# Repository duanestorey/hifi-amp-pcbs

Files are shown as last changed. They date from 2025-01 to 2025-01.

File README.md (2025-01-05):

## Hi-Fidelity Amplifier With Active-Crossovers and Room Correction

These are the PCBs representing a two-year passive effort to create, from scratch, an entire hi-fi amplifier with built-in DSP support for active crossovers and room 
correction.  You can [explore the individual PCBs for this project here](/pcbs).

### Overview

The amplifier has the following specifications:

* Four LM3886 68W amplifier channels in two monoblocks
* Five line-level RCA analog inputs
* One phono/vinyl RCA input with built-in amplifier and RIAA correction
* Four 192kHz/24-bit digital SPDIF inputs and one TOSLINK optical
* Multiple 192kHz/24-bit Burr-brown digital to analog converters
* IR remote connection, and built-in web server for configuration and web-app access
* Custom digital signal processor with active-crossovers and room correction ability based on biquad filters and parametric EQ
* Over-the-air code updates and wifi diagnostic information 

### Project Style Guide

#### Power Monitors

There are several INA260 power meters.  

1) MAIN Digital/Analog PSU monitor, address GND/SCL
2) MAIN Positive rail for channel amplifiers, address SCL/GND
3) 7V to 5V converter, address GND/GND
4) 7V to 3V converter, address GND/3V
5) Positive analog converter,  3V/GND
6) Entire 7V converter, 3V/3V

#### Temperature Sensors

1) Microprocessor board, address GND/GND
2) Digital/Analog PSU, address GND/3V#
3) Monoblocks 1, address 3V3/GND and 3V3/3V3
4) DSP, address float/GND

#### LED lights and resistors

The following voltages and LED colours should be used for consistency. In general, all LEDs are set at 2ma of current are 0603 size.

##### Digital Voltages

- 3.3V - Blue, set to ~2ma using 150R 
- 5.0V - Red, set to ~2ma using 1.3K

##### Analog Voltages

* +3.3V - Yellow, set to ~2ma using 620R
* +9.5V - Yellow, set to ~2ma using 3.6K
* -9.5V - Blue, set to ~2ma using 3.3K
* +34V - Yellow, set to ~2ma using 16K
* -34V - Blue, set to ~2ma using 16K
* 12V - Red, set to ~2ma using 4.7K
* Positive DC - Yellow, set to 2ma
* Negative DC - Blue, set to 2ma

#### SPDIF

- TODO: ADded more inputs
- TODO: Maybe add isolation transformers
- TODO: Change ground plane so SPDIF ground doesn't interfere with analog DAC ground

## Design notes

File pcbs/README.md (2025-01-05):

## Printed Circuit Boards

These are all the associated PCBs for the amplifier project.  They were all created in Kicad, and the boards optimized for production via JLCPCB.

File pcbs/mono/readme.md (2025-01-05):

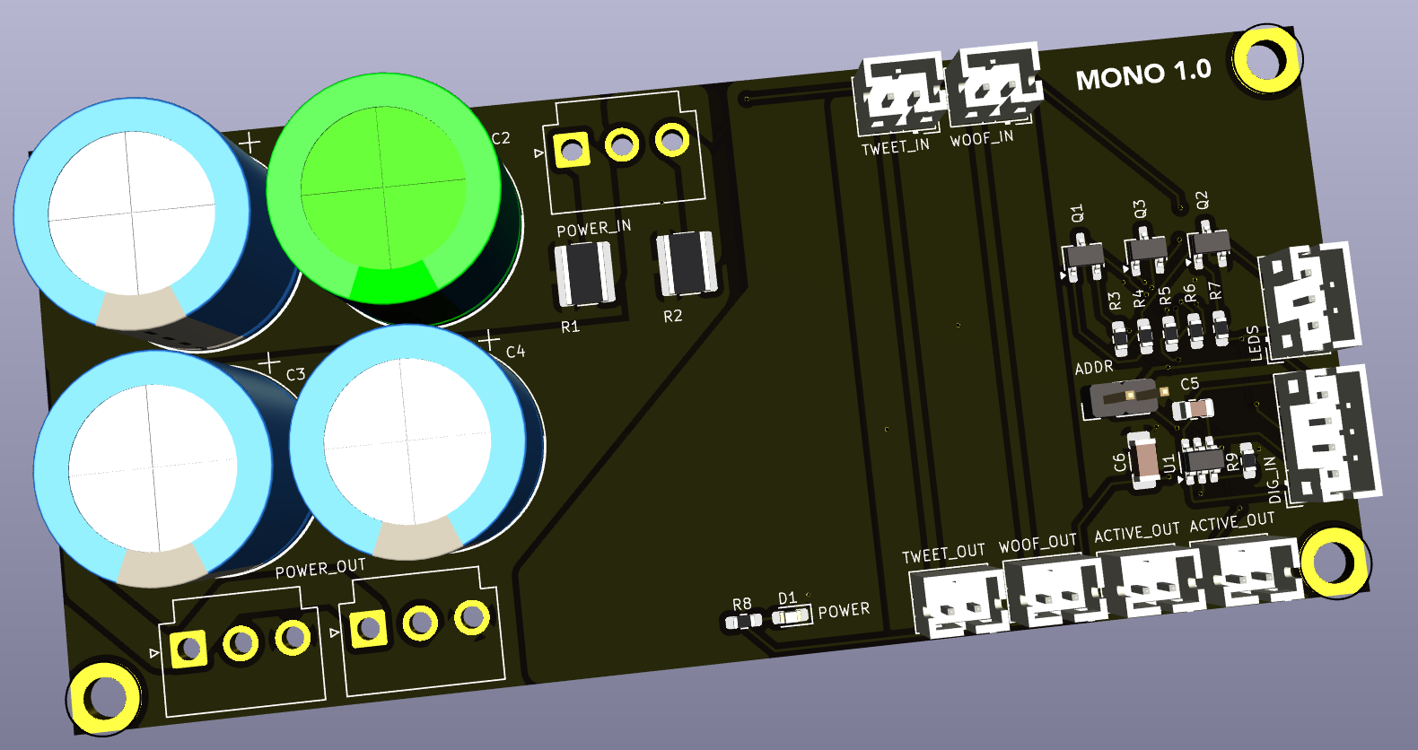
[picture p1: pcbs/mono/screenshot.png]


## Monoblocks

This board receives the main 7-pin XLR connections from the amplifier, which contain power, communincation, and control data.

### Version History

- 1.0: Initial Release

### Speciality Components

* TMP100 temperature sensor

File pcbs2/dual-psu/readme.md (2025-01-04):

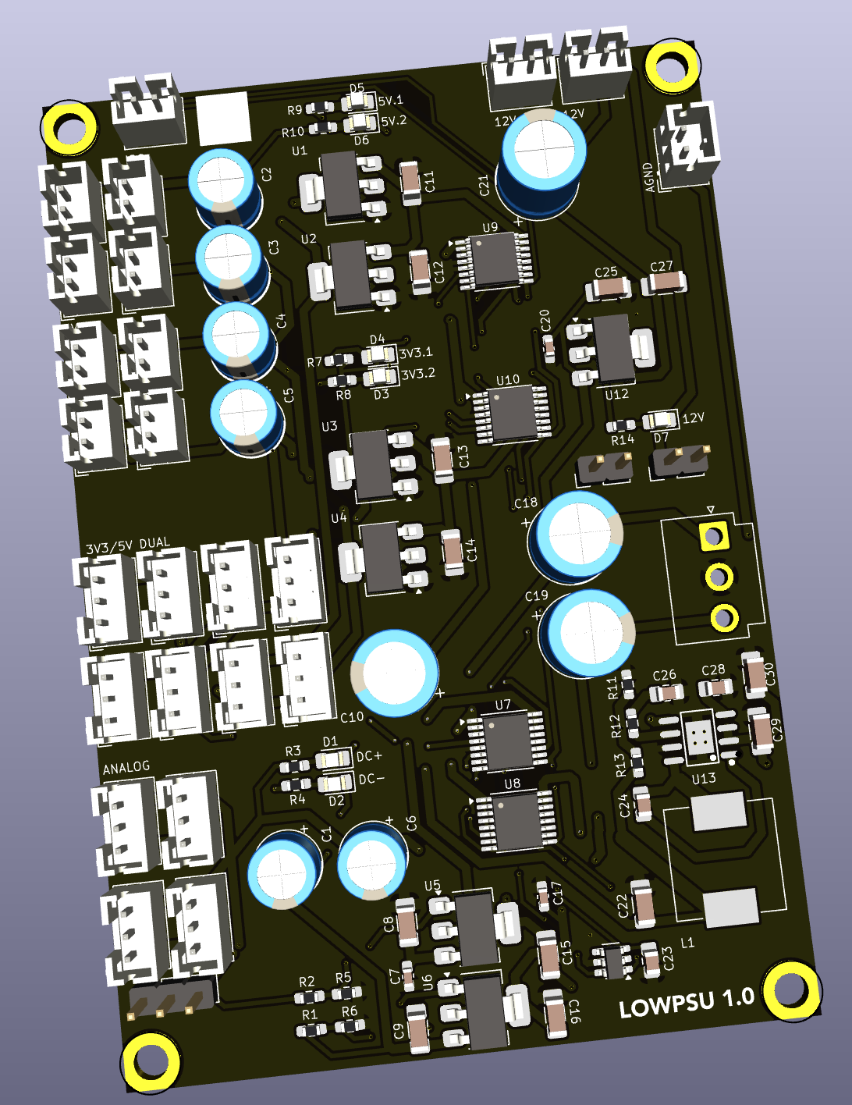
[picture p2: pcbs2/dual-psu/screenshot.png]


## Analog Power Supply for Operation Amplifier

This board produces a +/- 6.5V supply to be used with the DAC filter and the phono RIAA/pre-amplifier PCBs

### Version History

- 1.0: Initial Release

### Speciality Components

* LM317 & LM337 variable voltage regulators
* Myrra 44091 1.5VA with dual 6V secondaries

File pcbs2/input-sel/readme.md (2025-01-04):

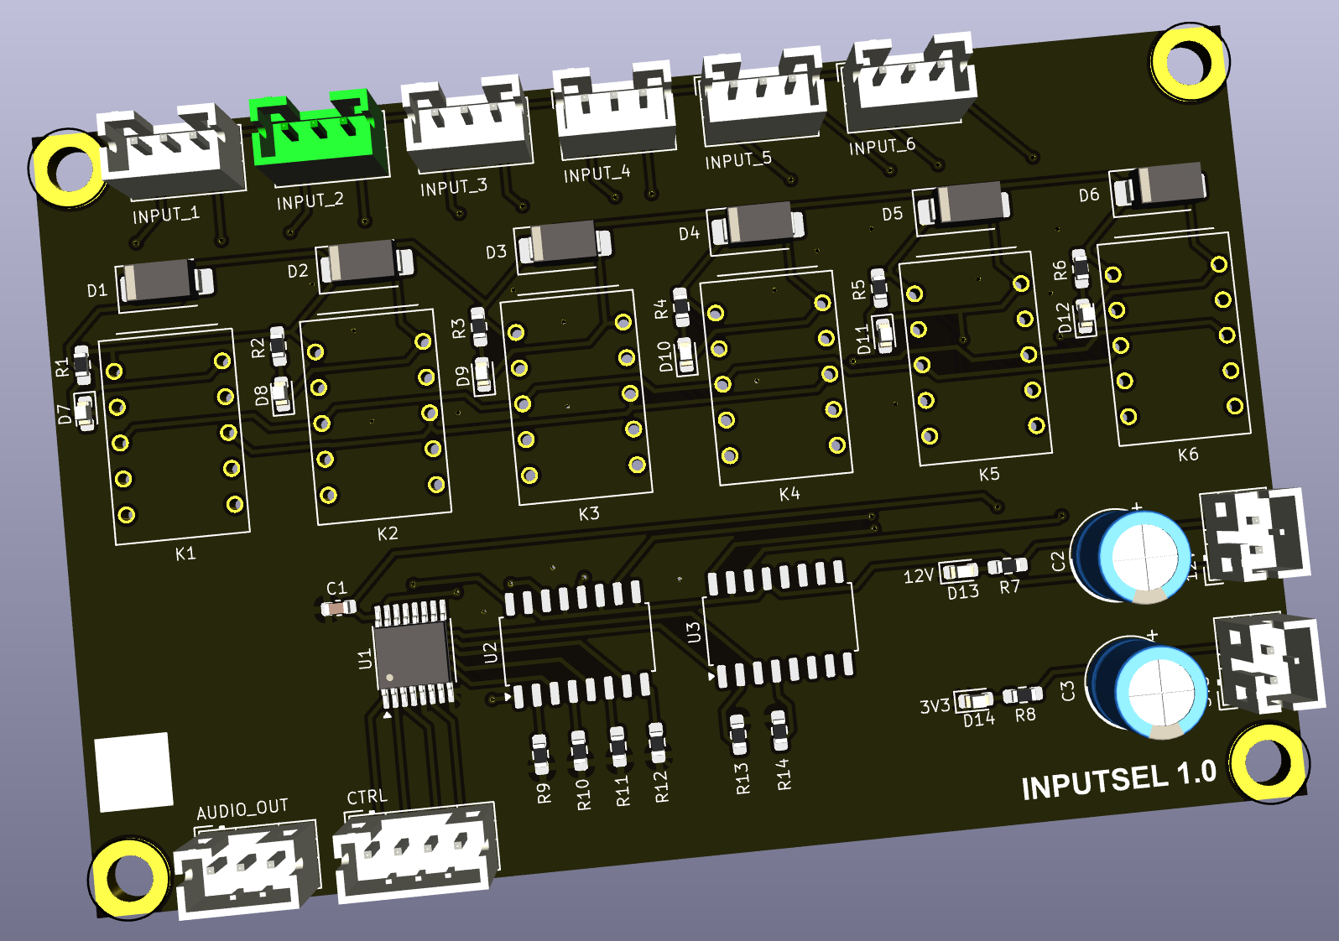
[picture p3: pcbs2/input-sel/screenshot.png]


## Line-Input Selector

This PCB allows switching of 4 analog stereo inputs and one 5.1 channel input into 5.1.  Channels that are missing
can be created.  It is based on the AX2358 IC.

### Version History

- 1.0: Initial Release
- 1.2: Did an initial build.  Seems like there is digital noise on the output, likely from the I2C signals sharing the audio ground.  This design now has a digital and analog ground on the board - it'll use the digital ground for the AX2358 IC, but use the analog ground for the channel outputs.

### Speciality Components

* AX2358 Channel switching IC
* Nichicon Muse ES 25V 10uF

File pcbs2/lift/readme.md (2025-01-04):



## Ground Lift

The heart of the amplifier is this microprocessor board based on the ESP32 WROOM 32 IC.

### Version History

- 1.0: Initial Release
- 1.1: Addressed issue with ESP32 programming transistors
- 1.2: Added missing pull-down resistor for relay/softstart 

### Speciality Components

* ESP32 WROOM 32
* FT232RL USB to UART converter
* TMP100 temperature sensor

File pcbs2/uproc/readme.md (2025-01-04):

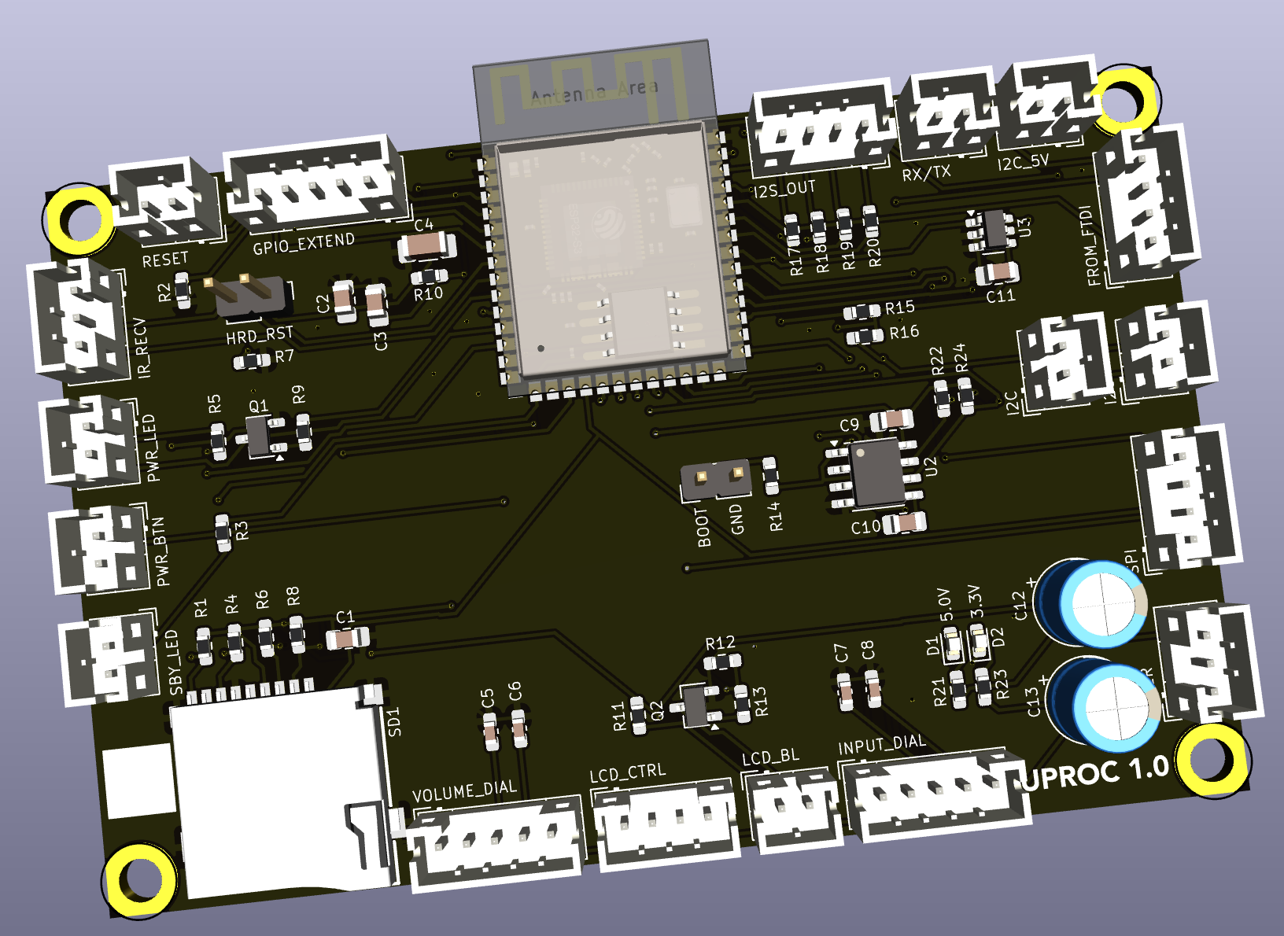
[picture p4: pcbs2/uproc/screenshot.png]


## Microprocessor Board

The heart of the amplifier is this microprocessor board based on the ESP32 WROOM 32 IC. Now supports a HAT.

### Version History

- 1.0: Initial Release
- 1.1: Addressed issue with ESP32 programming transistors
- 1.2: Added missing pull-down resistor for relay/softstart 

### Speciality Components

* ESP32 WROOM 32
* FT232RL USB to UART converter
* TMP100 temperature sensor

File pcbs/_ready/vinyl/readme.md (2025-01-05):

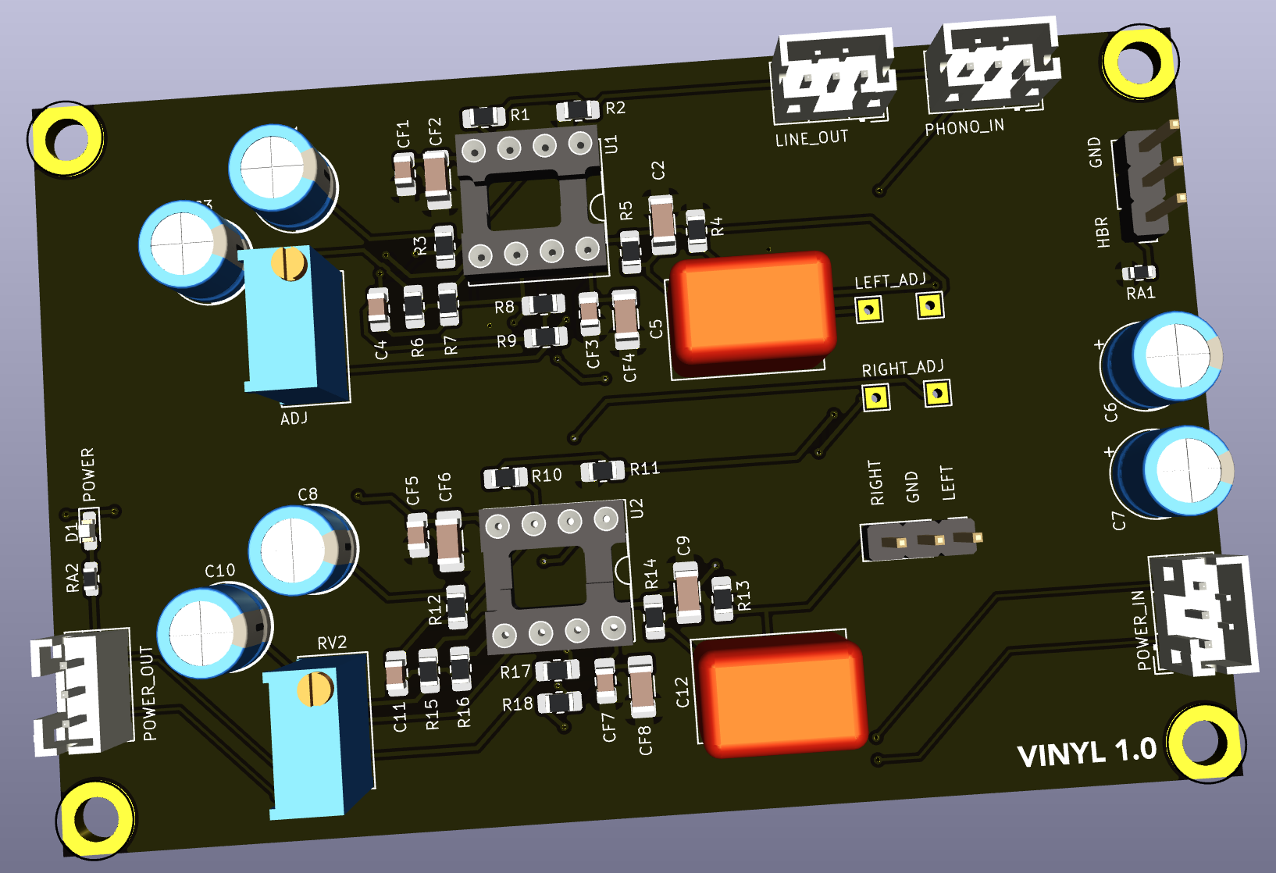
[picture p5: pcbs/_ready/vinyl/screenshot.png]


## Phono/Vinyl Pre-amp

This is a phono/vinyl pre-amp with adjustable gain from about 40dB up to 60dB. It is based almost entirely on the ESP Project 6 Hifi Phono Pre-amp.  All resistors are thin-film 603/805, and all capacitors are either Nichicon Muse ES bipolar electrolytics or C0G surface mount 1206 variants.

### Version History

- 1.0: Initial Release

### Speciality Components

* OPA1612 Burr Brown operation amplifiers
* Various C0G and thin film resistors
* Nichicon Muse ES 25V 10uF

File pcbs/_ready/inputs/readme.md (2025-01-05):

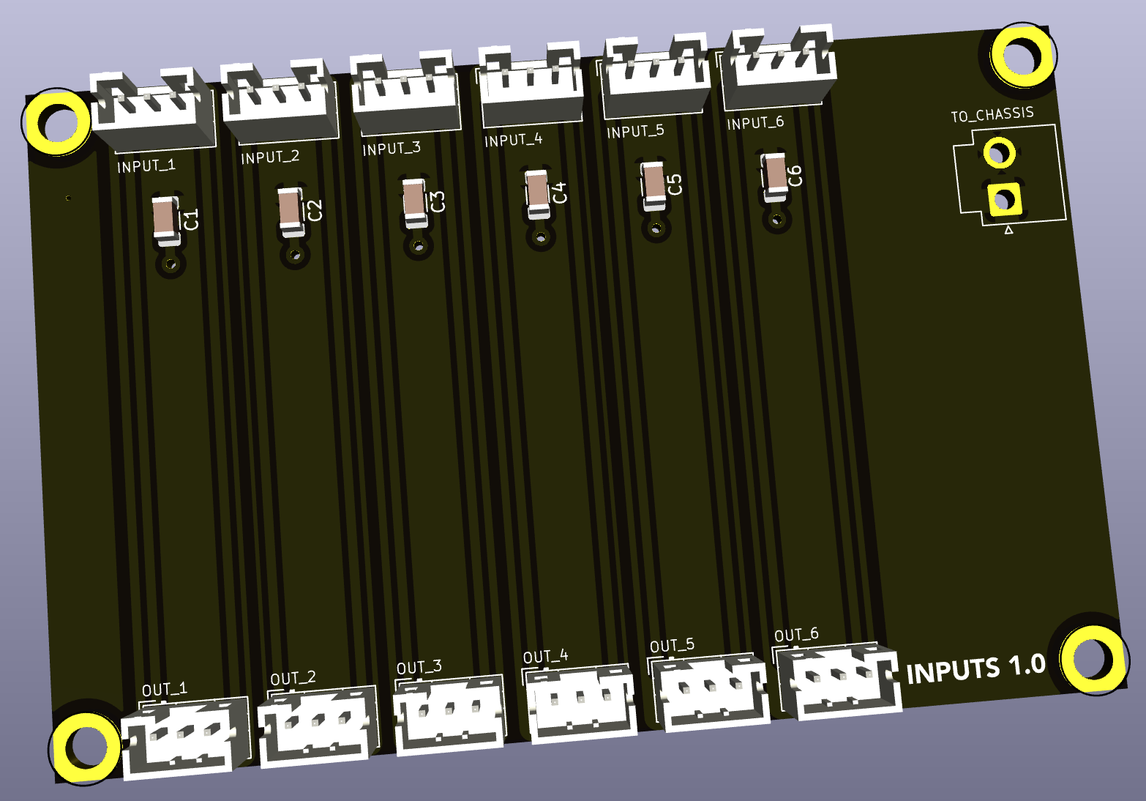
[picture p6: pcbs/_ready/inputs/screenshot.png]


# Input board

This is a simple board meant to proxy six RCA input signals from one part of the amplifier to the other without long physical cable runs. It also provides a chassis GND connection via a capacitor to shunt stray EMI to chassis ground.

## Version History

- 1.0: Initial Release

## Speciality Components

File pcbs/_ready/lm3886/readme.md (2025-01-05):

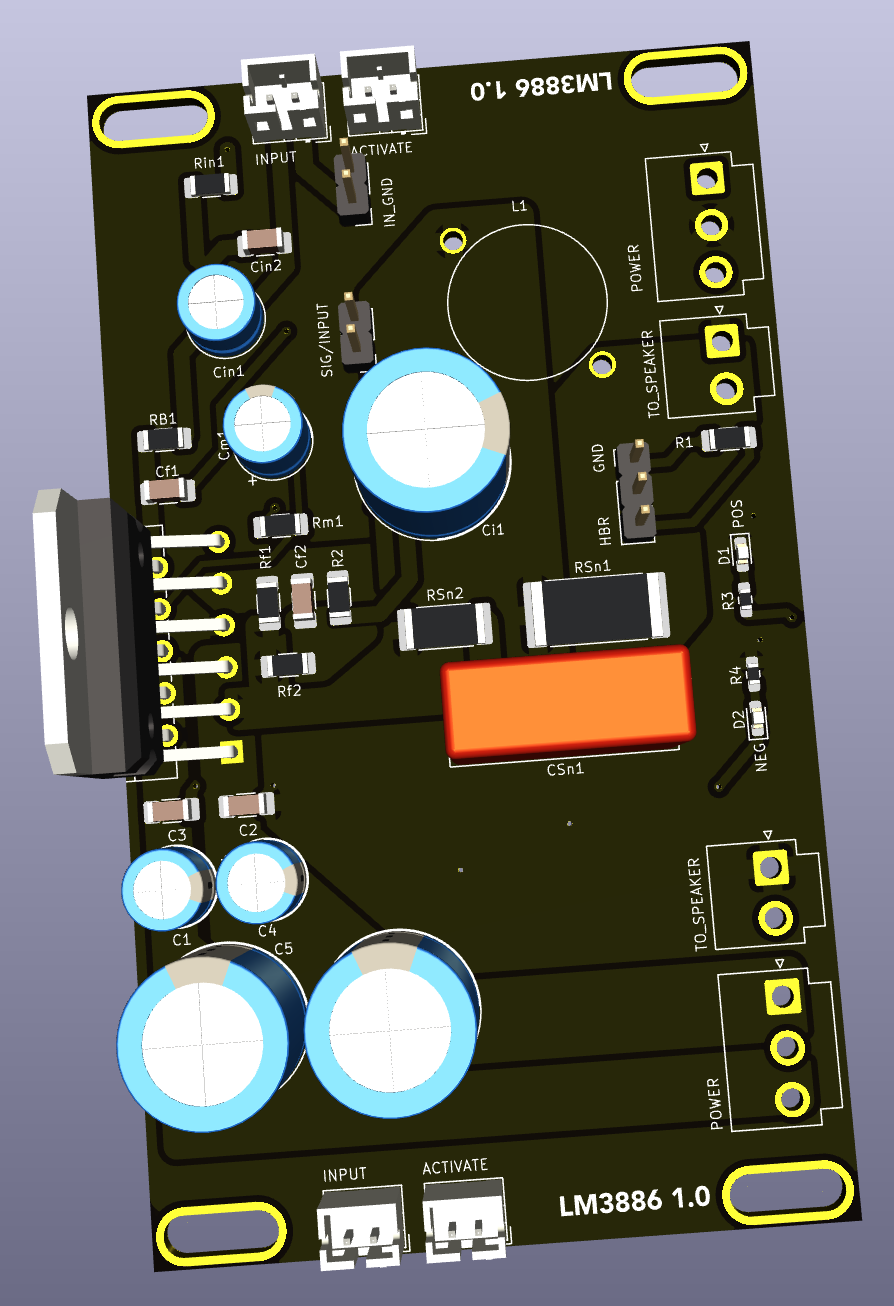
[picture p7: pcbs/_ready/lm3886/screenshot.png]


## LM3886

This board is meant to be reversable (top-to-bottom), and contains the highly rated, high fidelity LM3886 audio amplifier IC. Two of these boards are used in each monoblock to amplifier the associated tweeter and woofer channels.

### Version History

- 1.0: Initial Release

### Speciality Components

* LM3886 68W audio amplifier IC
* 500nH air core Inductor

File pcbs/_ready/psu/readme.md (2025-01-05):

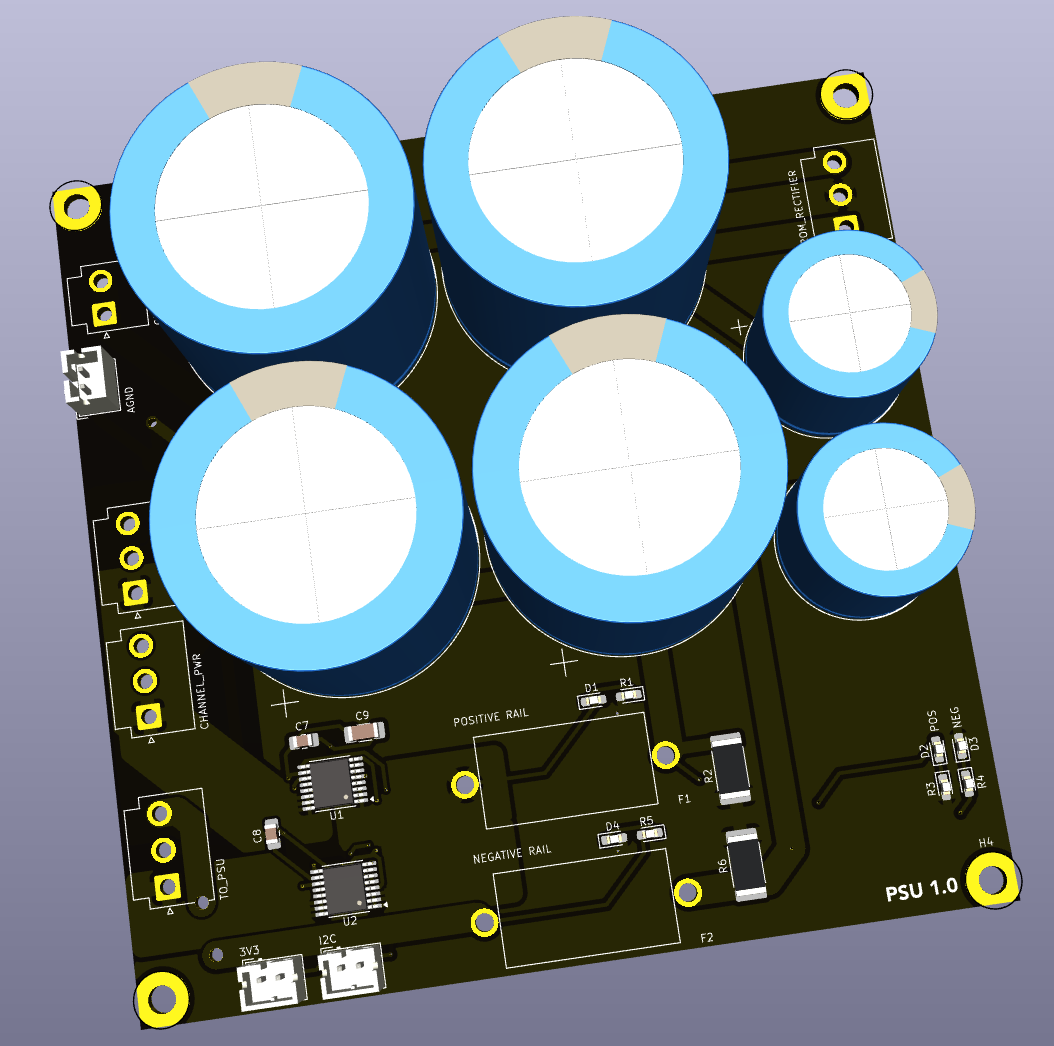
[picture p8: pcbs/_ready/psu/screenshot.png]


## Main Amplifier Channel Power Supply

This board is the main power reservoir for the main +/- 32V power supplies.  

### Version History

- 1.0: Initial Release

### Speciality Components

* 30x50mm 15000uF 50V capacitors
* 5x20mm fuse holders
* 2x INA260 current monitors

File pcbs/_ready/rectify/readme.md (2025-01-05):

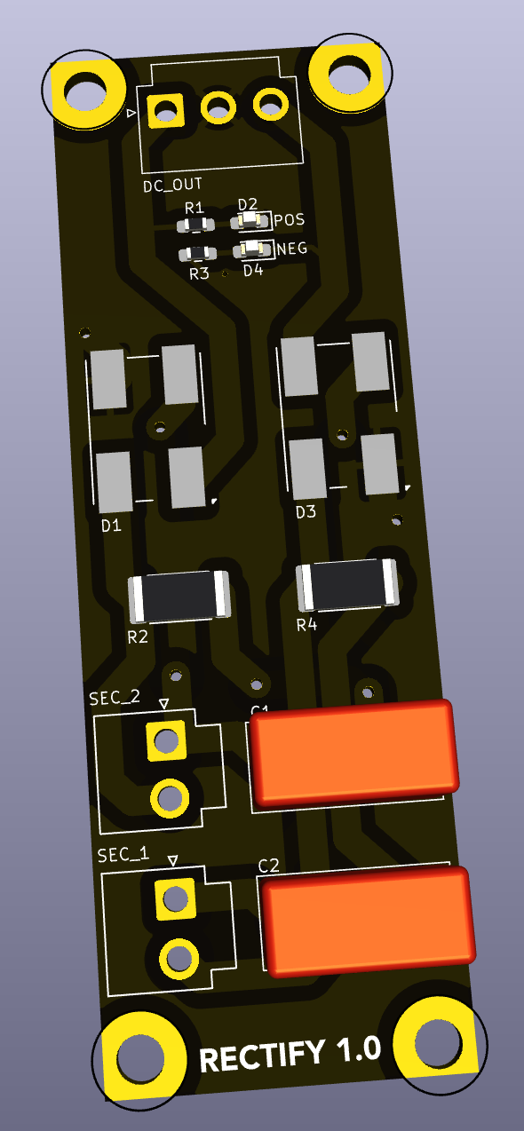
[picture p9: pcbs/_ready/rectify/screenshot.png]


## Main Rectifier

This board takes the output from the toroid transformer and converts it into DC voltage to use with the channel amplifiers.  This was separated out to free up room on the main power supply board with the capacitor bank, and also allows easy changes in the future to alterate rectification configurations such as an ideal diode bridge.

### Version History

- 1.0: Initial Release

### Speciality Components

* MP1010G-G 1000V/10A bridge rectifier
* 100nF WIMA snubber capacitor

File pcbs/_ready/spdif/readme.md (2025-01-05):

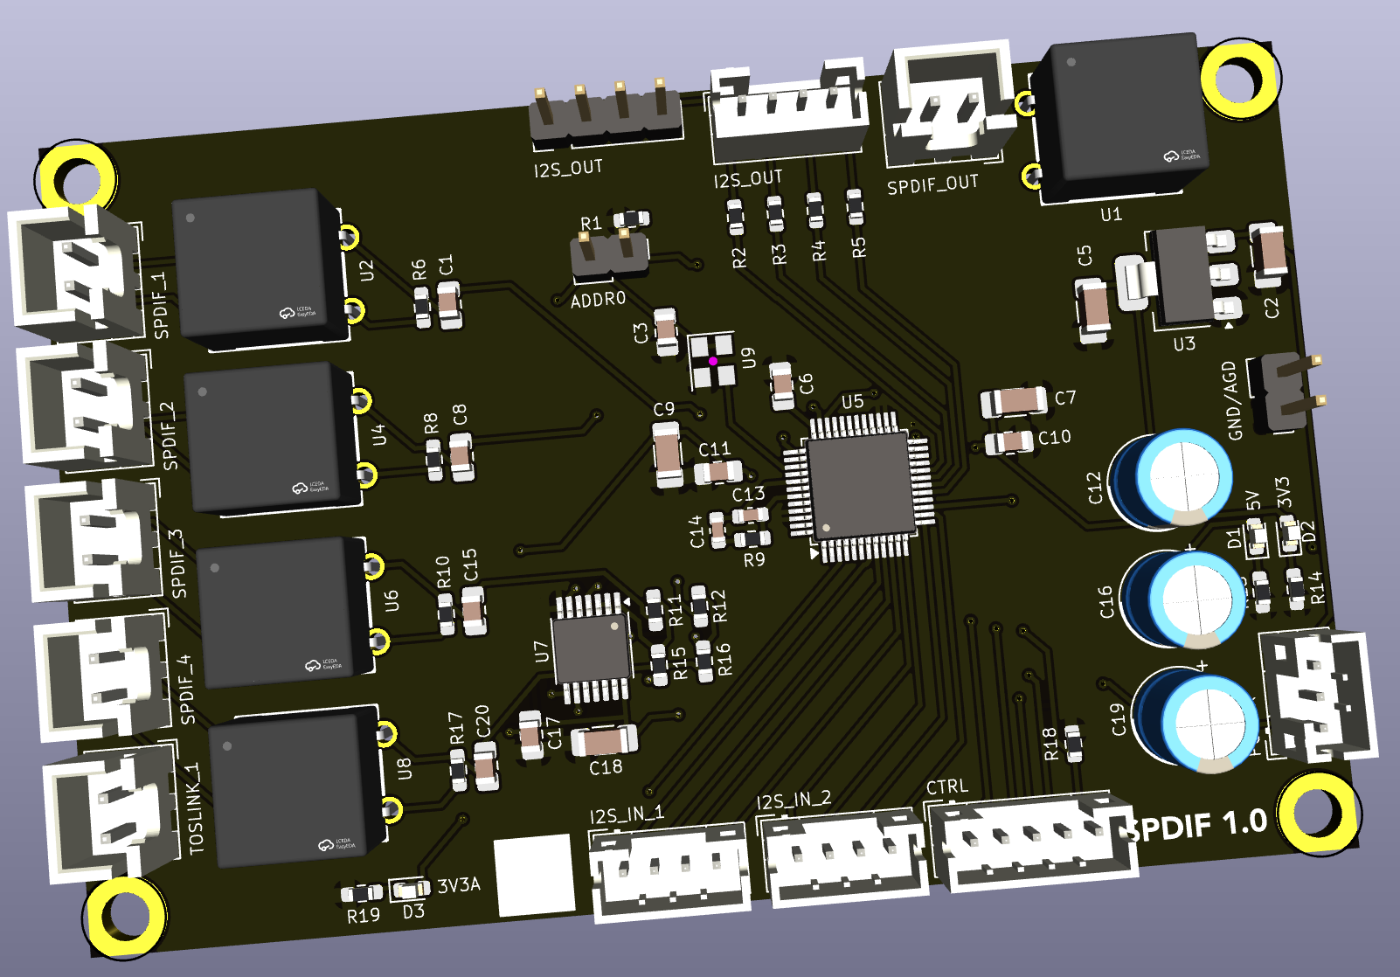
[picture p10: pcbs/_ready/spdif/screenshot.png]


## SPDIF transceiver 

This board provides decoding for up to 5 SPDIF/TOSLINK digital audio connections.  It allows has two I2S inputs (one for the microprocessor, and one from the analog ADC board) which can be routed to the output.  It also has on digital SDPIF output for future use/expansion.

### Version History

- 1.0: Initial Release

### Speciality Compenents

* DIX9211 216-kHz Digital Audio Interface Transceiver

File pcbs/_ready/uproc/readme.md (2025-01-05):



## Microprocessor Board

The heart of the amplifier is this microprocessor board based on the ESP32 WROOM-S3 IC. 

### Version History

- 1.0: Initial Release

### Speciality Components

* ESP32 WROOM 32
* TMP100 temperature sensor
* TCA9517DR level shifter for I2C bus
* TF-115-BCP9 micro SD card reader

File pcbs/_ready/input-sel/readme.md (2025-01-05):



## Line-Input Selector

This PCB allows switching of 6 analog stereo inputs using gold-plated small signal relays.

### Version History

- 1.0: Initial Release

### Speciality Components

* 6x KEMET EA2 12V relays
* 2x TCMT4600 quad optocoupler
* CD74AC238 3->8 digital decoder

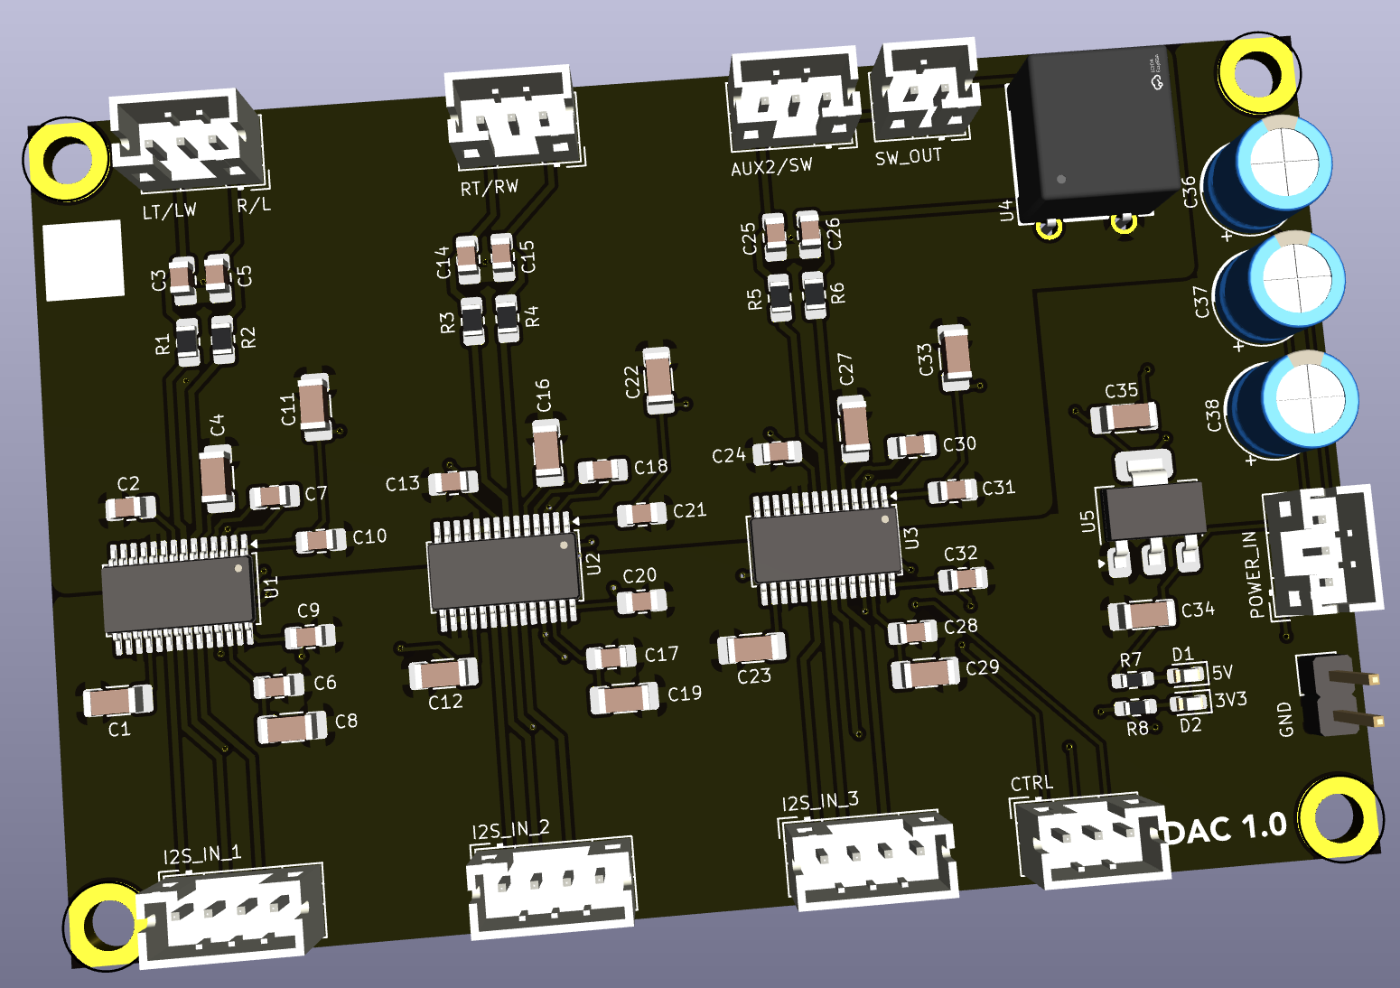
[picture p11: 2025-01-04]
pcbs/_ready/dac/screenshot.png

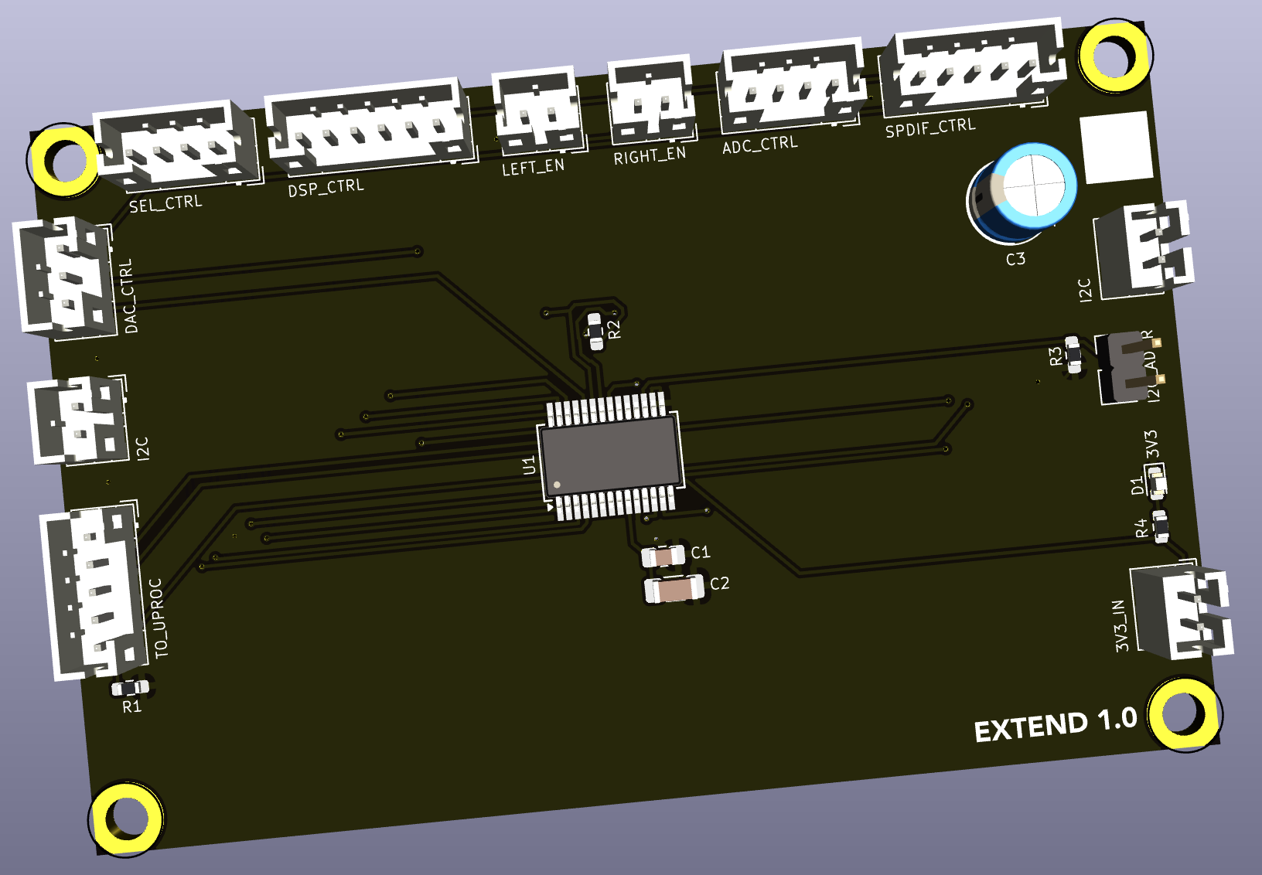
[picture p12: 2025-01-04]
pcbs/_ready/extend/screenshot.png

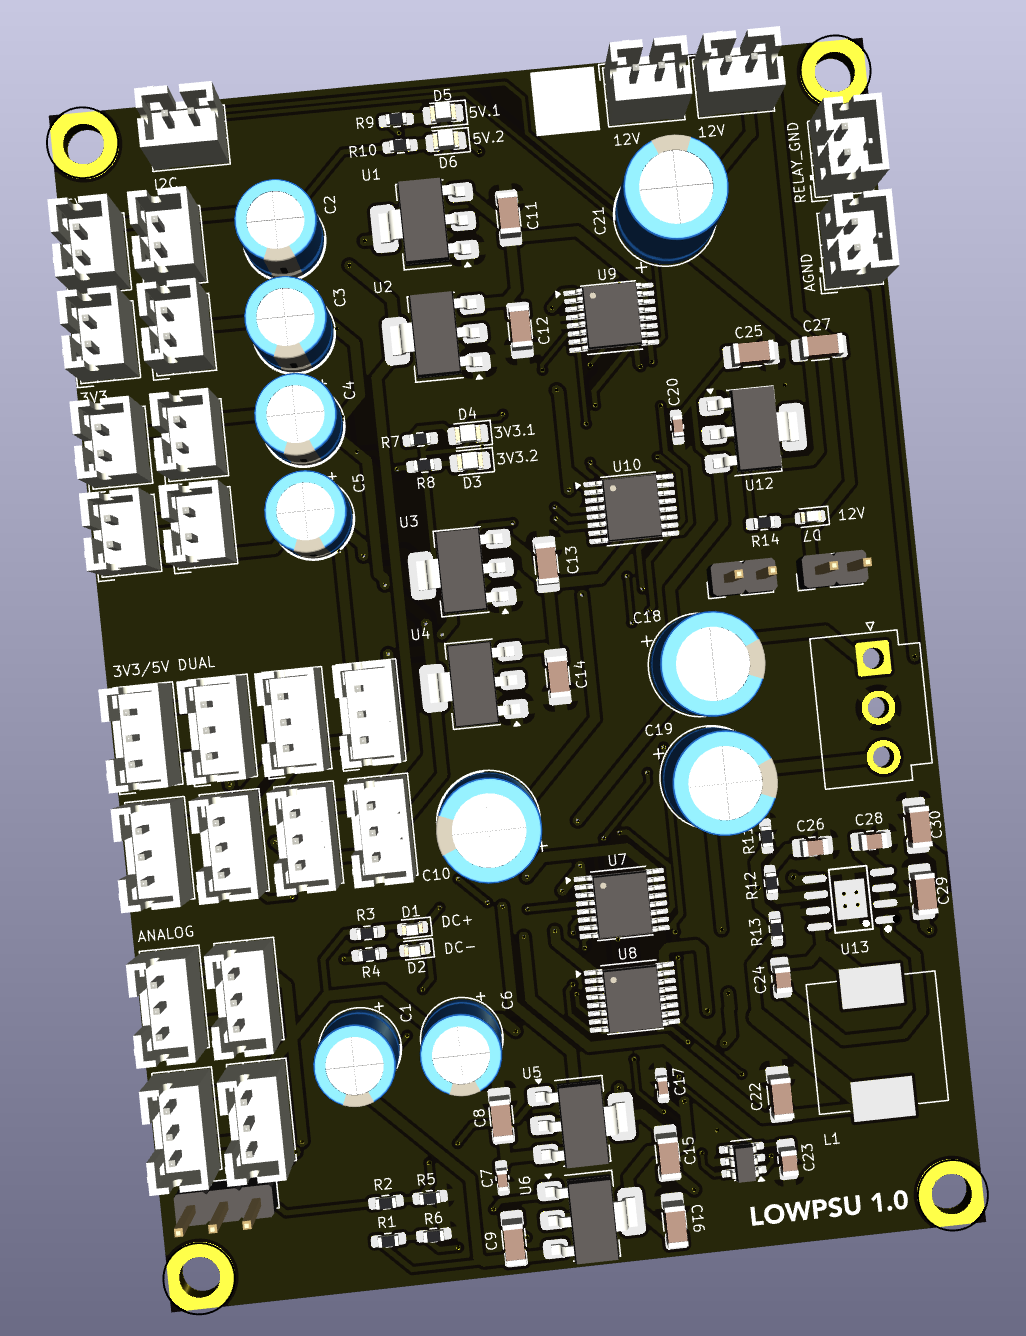
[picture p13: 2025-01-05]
pcbs/_ready/dual-psu/screenshot.png

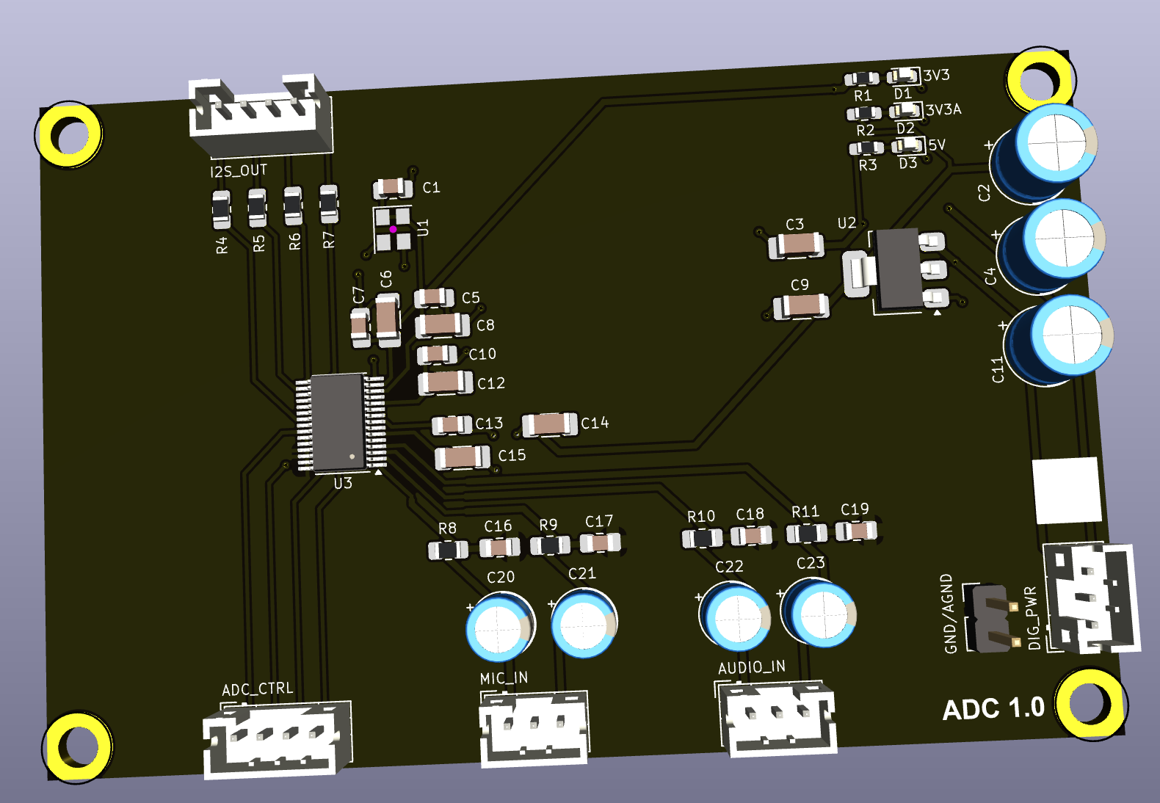
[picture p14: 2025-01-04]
pcbs/_ready/adc/screenshot.png

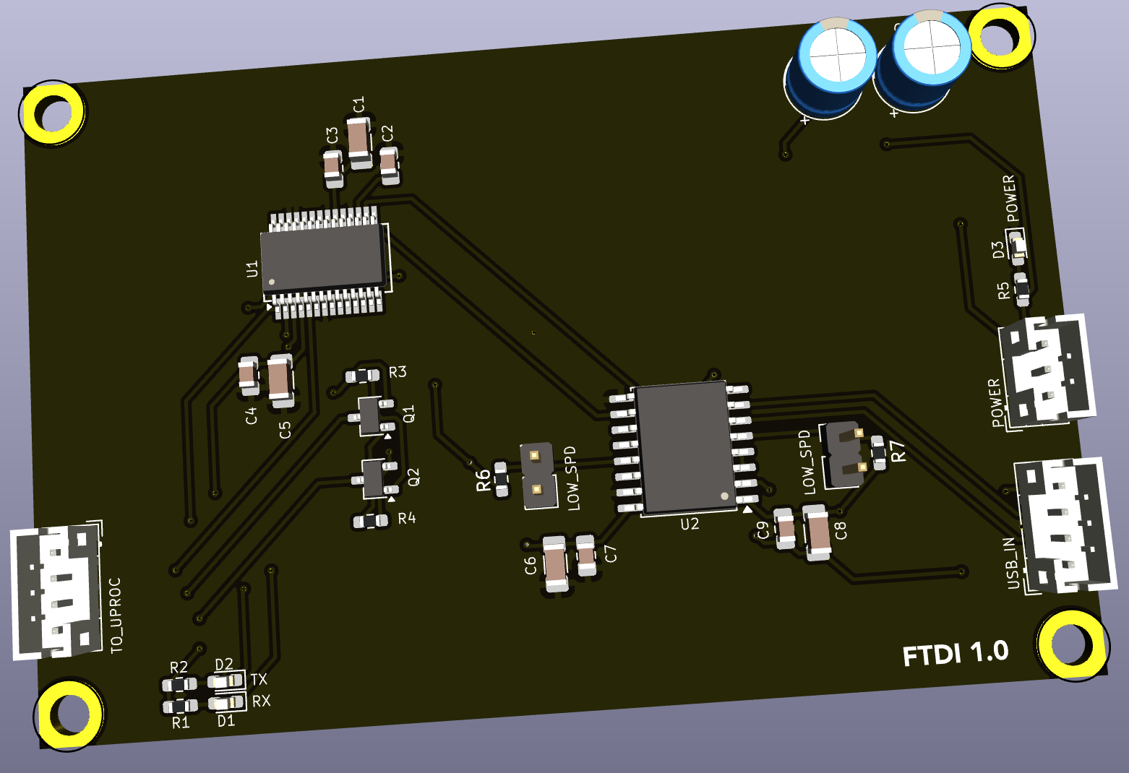
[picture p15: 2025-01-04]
pcbs/_ready/ftdi/screenshot.png

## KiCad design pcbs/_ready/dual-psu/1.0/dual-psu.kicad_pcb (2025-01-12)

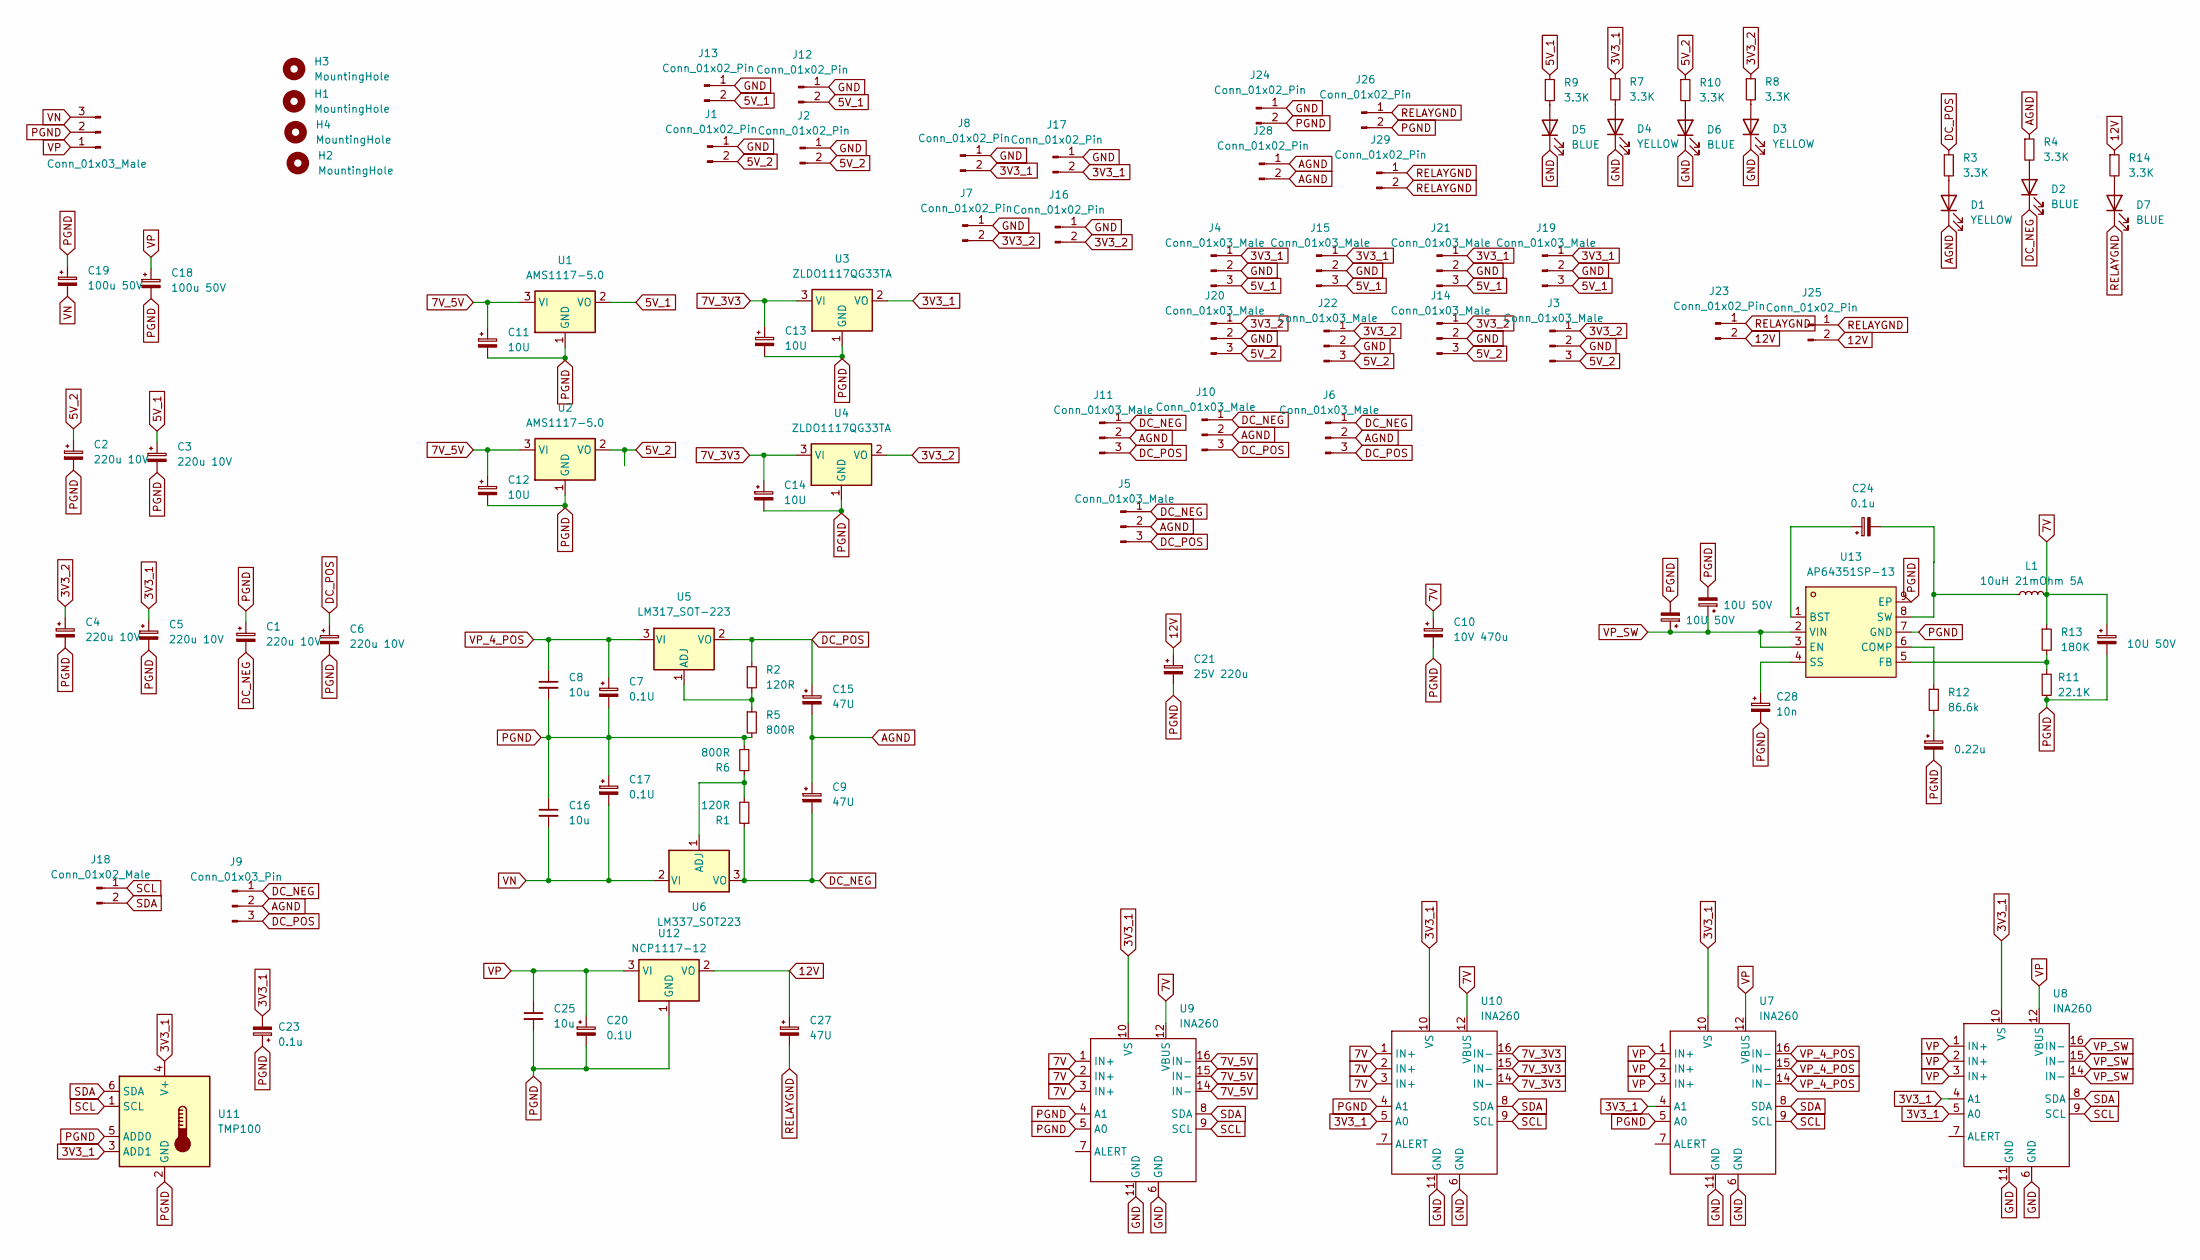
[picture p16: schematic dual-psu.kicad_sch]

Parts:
C1, C2, C3, C4, C5, C6: 220u 10V; CP_Radial_D6.3mm_P2.50mm
C7, C17, C20: 0.1U; C_0603_1608Metric_Pad1.08x0.95mm_HandSolder
C8, C16, C25: 10u; C_1206_3216Metric_Pad1.33x1.80mm_HandSolder
C9, C15, C27: 47U; C_1206_3216Metric_Pad1.33x1.80mm_HandSolder
C10: 10V 470u; CP_Radial_D8.0mm_P3.50mm
C11, C12, C13, C14: 10U; C_1206_3216Metric_Pad1.33x1.80mm_HandSolder
C18, C19: 100u 50V; CP_Radial_D8.0mm_P3.50mm
C21: 25V 220u; CP_Radial_D8.0mm_P3.50mm
C22, C29, C30: 10U 50V; C_1206_3216Metric_Pad1.33x1.80mm_HandSolder
C23, C24: 0.1u; C_0805_2012Metric_Pad1.18x1.45mm_HandSolder
C26: 0.22u; C_0805_2012Metric_Pad1.18x1.45mm_HandSolder
C28: 10n; C_0805_2012Metric_Pad1.18x1.45mm_HandSolder
D1: YELLOW; LED_0603_1608Metric
D2, D7: BLUE; LED_0603_1608Metric
D3, D4: YELLOW; LED_0805_2012Metric_Pad1.15x1.40mm_HandSolder
D5, D6: BLUE; LED_0805_2012Metric_Pad1.15x1.40mm_HandSolder
H1, H2, H3, H4: MountingHole; MountingHole_3.2mm_M3_DIN965_Pad_TopOnly
J1, J2, J7, J8, J12, J13, J16, J17, J23, J25, J28, J29: Conn_01x02_Pin; JST_PH_B2B-PH-K_1x02_P2.00mm_Vertical
J3, J4, J5, J6, J10, J11, J14, J15, J19, J20, J21, J22: Conn_01x03_Male; JST_PH_B3B-PH-K_1x03_P2.00mm_Vertical
J9: Conn_01x03_Pin; PinHeader_1x03_P2.54mm_Vertical
J18: Conn_01x02_Male; JST_PH_B2B-PH-K_1x02_P2.00mm_Vertical
J24, J26: Conn_01x02_Pin; PinHeader_1x02_P2.54mm_Vertical
J27: Conn_01x03_Male; JST_VH_B3P-VH_1x03_P3.96mm_Vertical
L1: 10uH 21mOhm 5A; L_Vishay_IHLP-4040; Mouser 704-DR1040-7R0-R
R1, R2: 120R; R_0603_1608Metric_Pad0.98x0.95mm_HandSolder
R3, R4, R7, R8, R9, R10, R14: 3.3K; R_0603_1608Metric_Pad0.98x0.95mm_HandSolder
R5, R6: 800R; R_0603_1608Metric_Pad0.98x0.95mm_HandSolder
R11: 22.1K; R_0603_1608Metric_Pad0.98x0.95mm_HandSolder; Mouser 603-RC0603JR-07820KP
R12: 86.6k; R_0603_1608Metric_Pad0.98x0.95mm_HandSolder; Mouser 71-CRCW0603-86.6K-E3
R13: 180K; R_0603_1608Metric_Pad0.98x0.95mm_HandSolder; Mouser 603-RC0603JR-10180KL
U1, U2: AMS1117-5.0; SOT-223-3_TabPin2; Mouser 926-LM1117MPX5.0NOPB
U3, U4: ZLDO1117QG33TA; SOT-223-3_TabPin2; Mouser ZLDO1117QG33TA
U5: LM317_SOT-223; SOT-223-3_TabPin2; Mouser 595-LM317DCY
U6: LM337_SOT223; SOT-223-3_TabPin2; Mouser 926-LM337IMPX/NOPB
U7, U8, U9, U10: INA260; TSSOP-16_4.4x5mm_P0.65mm
U11: TMP100; SOT-23-6; Mouser 595-TMP100NA/3K
U12: NCP1117-12; SOT-223; Mouser 863-NCP1117ST12T3G
U13: AP64351SP-13; SOIC-8_L4.9-W3.9-P1.27-LS6.0-BL-EP; LCSC Part C3192339

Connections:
3V3_1: C5.1, C23.2, J4.1, J8.2, J15.1, J17.2, J19.1, J21.1, R7.1, U3.2 (VO), U7.4 (A1), U7.10 (VS), U8.4 (A1), U8.5 (A0), U8.10 (VS), U9.10 (VS), U10.5 (A0), U10.10 (VS), U11.3 (ADD1), U11.4 (V+)
3V3_2: C4.1, J3.1, J7.2, J14.1, J16.2, J20.1, J22.1, R8.1, U4.2 (VO)
5V_1: C3.1, J4.3, J12.2, J13.2, J15.3, J19.3, J21.3, R9.1, U1.2 (VO)
5V_2: C2.1, J1.2, J2.2, J3.3, J14.3, J20.3, J22.3, R10.1, U2.2 (VO)
7V: C10.1, C22.1, L1.2, R13.1, U9.1 (IN+), U9.2 (IN+), U9.3 (IN+), U9.12 (VBUS), U10.1 (IN+), U10.2 (IN+), U10.3 (IN+), U10.12 (VBUS)
7V_3V3: C13.1, C14.1, U3.3 (VI), U4.3 (VI), U10.14 (IN-), U10.15 (IN-), U10.16 (IN-)
7V_5V: C11.1, C12.1, U1.3 (VI), U2.3 (VI), U9.14 (IN-), U9.15 (IN-), U9.16 (IN-)
12V: C21.1, C27.1, J23.2, J25.2, R14.1, U12.2 (VO)
AGND: C9.1, C15.2, D1.1 (K), J5.2, J6.2, J9.2, J10.2, J11.2, J28.1, J28.2, R4.1
DC_NEG: C1.2, C9.2, D2.1 (K), J5.1, J6.1, J9.1, J10.1, J11.1, R1.1, U6.3 (VO)
DC_POS: C6.1, C15.1, J5.3, J6.3, J9.3, J10.3, J11.3, R2.1, R3.1, U5.2 (VO)
GND: D3.1 (K), D4.1 (K), D5.1 (K), D6.1 (K), J1.1, J2.1, J3.2, J4.2, J7.1, J8.1, J12.1, J13.1, J14.2, J15.2, J16.1, J17.1, J19.2, J20.2, J21.2, J22.2, J24.1, U7.6 (GND), U7.11 (GND), U8.6 (GND), U8.11 (GND), U9.6 (GND), U9.11 (GND), U10.6 (GND), U10.11 (GND)
unnamed: C26.1, R12.2
unnamed: D1.2 (A), R3.2
unnamed: D2.2 (A), R4.2
unnamed: D3.2 (A), R8.2
unnamed: D4.2 (A), R7.2
unnamed: D5.2 (A), R9.2
unnamed: D6.2 (A), R10.2
unnamed: D7.2 (A), R14.2
unnamed: R2.2, R5.1, U5.1 (ADJ)
unnamed: R1.2, R6.1, U6.1 (ADJ)
unnamed: C24.1, U13.1 (BST)
unnamed: R12.1, U13.6 (COMP)
unnamed: R11.1, R13.2, U13.5 (FB)
unnamed: C28.1, U13.4 (SS)
unnamed: C24.2, L1.1, U13.8 (SW)
PGND: C1.1, C2.2, C3.2, C4.2, C5.2, C6.2, C7.2, C8.2, C10.2, C11.2, C12.2, C13.2, C14.2, C16.1, C17.1, C18.2, C19.1, C20.2, C21.2, C22.2, C23.1, C25.2, C26.2, C28.2, C29.2, C30.2, J24.2, J26.2, J27.2, R5.2, R6.2, R11.2, U1.1 (GND), U2.1 (GND), U3.1 (GND), U4.1 (GND), U7.5 (A0), U9.4 (A1), U9.5 (A0), U10.4 (A1), U11.2 (GND), U11.5 (ADD0), U12.1 (GND), U13.7 (GND), U13.9 (EP)
RELAYGND: C27.2, D7.1 (K), J23.1, J25.1, J26.1, J29.1, J29.2
SCL: J18.1, U7.9 (SCL), U8.9 (SCL), U9.9 (SCL), U10.9 (SCL), U11.1 (SCL)
SDA: J18.2, U7.8 (SDA), U8.8 (SDA), U9.8 (SDA), U10.8 (SDA), U11.6 (SDA)
VN: C16.2, C17.2, C19.2, J27.3, U6.2 (VI)
VP: C18.1, C20.1, C25.1, J27.1, U7.1 (IN+), U7.2 (IN+), U7.3 (IN+), U7.12 (VBUS), U8.1 (IN+), U8.2 (IN+), U8.3 (IN+), U8.12 (VBUS), U12.3 (VI)
VP_4_POS: C7.1, C8.1, U5.3 (VI), U7.14 (IN-), U7.15 (IN-), U7.16 (IN-)
VP_SW: C29.1, C30.1, U8.14 (IN-), U8.15 (IN-), U8.16 (IN-), U13.2 (VIN), U13.3 (EN)

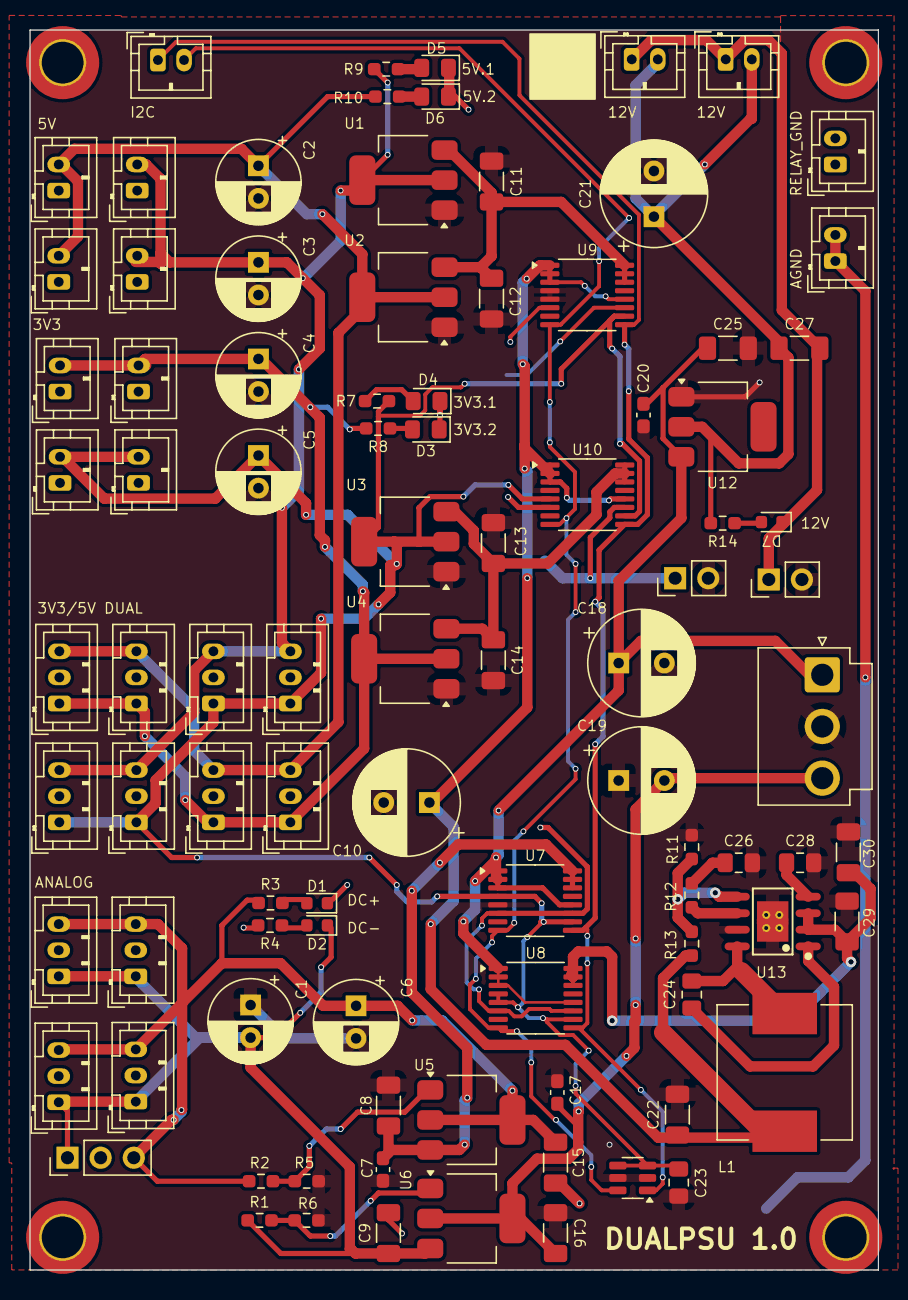
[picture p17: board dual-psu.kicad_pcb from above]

Board: 2 copper layers, 65.0 x 95.0 mm, 98 parts (0 on the bottom side), 35 nets.

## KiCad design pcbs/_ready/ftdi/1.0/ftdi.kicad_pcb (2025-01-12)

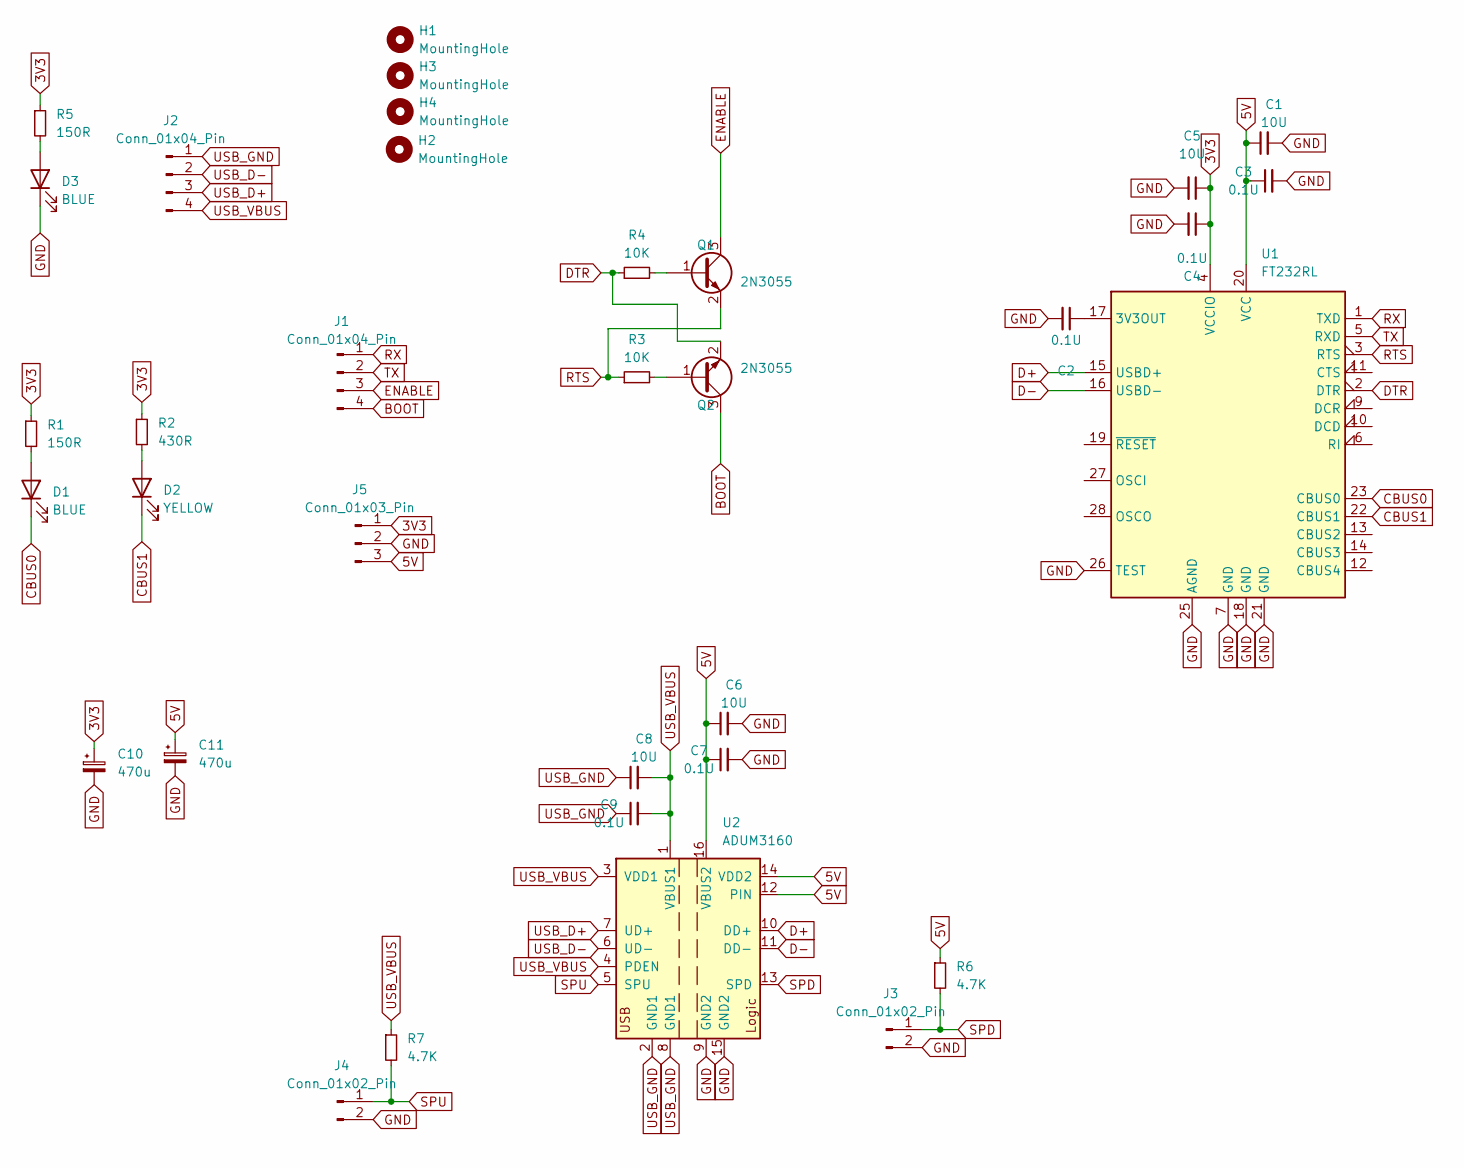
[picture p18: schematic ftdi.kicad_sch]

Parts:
C1, C5, C6, C8: 10U; C_1206_3216Metric_Pad1.33x1.80mm_HandSolder
C2, C3, C4, C7, C9: 0.1U; C_0805_2012Metric_Pad1.18x1.45mm_HandSolder
C10, C11: 470u; CP_Radial_D6.3mm_P2.50mm
D1, D3: BLUE; LED_0603_1608Metric_Pad1.05x0.95mm_HandSolder; LCSC XL-1608UBC-04
D2: YELLOW; LED_0603_1608Metric_Pad1.05x0.95mm_HandSolder; LCSC XL-1608UBC-04
H1, H2, H3, H4: MountingHole; MountingHole_3.2mm_M3_DIN965_Pad_TopOnly
J1, J2: Conn_01x04_Pin; JST_PH_B4B-PH-K_1x04_P2.00mm_Vertical
J3, J4: Conn_01x02_Pin; PinHeader_1x02_P2.54mm_Vertical
J5: Conn_01x03_Pin; JST_PH_B3B-PH-K_1x03_P2.00mm_Vertical
Q1, Q2: 2N3055; TSOT-23
R1, R5: 150R; R_0603_1608Metric_Pad0.98x0.95mm_HandSolder
R2: 430R; R_0603_1608Metric_Pad0.98x0.95mm_HandSolder
R3, R4: 10K; R_0603_1608Metric_Pad0.98x0.95mm_HandSolder
R6, R7: 4.7K; R_0603_1608Metric_Pad0.98x0.95mm_HandSolder
U1: FT232RL; SSOP-28_5.3x10.2mm_P0.65mm
U2: ADUM3160; SOIC-16W_7.5x10.3mm_P1.27mm; Mouser 584-ADUM3160BRWZ-R

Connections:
3V3: C4.1, C5.1, C10.1, J5.1, R1.1, R2.1, R5.1, U1.4 (VCCIO)
5V: C1.1, C3.1, C6.1, C7.1, C11.1, J5.3, R6.1, U1.20 (VCC), U2.12 (PIN), U2.14 (VDD2), U2.16 (VBUS2)
BOOT: J1.4, Q2.3 (C)
CBUS0: D1.1 (K), U1.23 (CBUS0)
CBUS1: D2.1 (K), U1.22 (CBUS1)
D+: U1.15 (USBD+), U2.10 (DD+)
D-: U1.16 (USBD-), U2.11 (DD-)
DTR: Q2.2 (E), R4.1, U1.2 (DTR)
ENABLE: J1.3, Q1.3 (C)
GND: C1.2, C2.2, C3.2, C4.2, C5.2, C6.2, C7.2, C10.2, C11.2, D3.1 (K), J3.2, J4.2, J5.2, U1.7 (GND), U1.18 (GND), U1.21 (GND), U1.25 (AGND), U1.26 (TEST), U2.9 (GND2), U2.15 (GND2)
unnamed: D1.2 (A), R1.2
unnamed: D2.2 (A), R2.2
unnamed: D3.2 (A), R5.2
unnamed: Q1.1 (B), R4.2
unnamed: Q2.1 (B), R3.2
unnamed: C2.1, U1.17 (3V3OUT)
RTS: Q1.2 (E), R3.1, U1.3 (RTS)
RX: J1.1, U1.1 (TXD)
SPD: J3.1, R6.2, U2.13 (SPD)
SPU: J4.1, R7.2, U2.5 (SPU)
TX: J1.2, U1.5 (RXD)
USB_D+: J2.3, U2.7 (UD+)
USB_D-: J2.2, U2.6 (UD-)
USB_GND: C8.1, C9.1, J2.1, U2.2 (GND1), U2.8 (GND1)
USB_VBUS: C8.2, C9.2, J2.4, R7.1, U2.1 (VBUS1), U2.3 (VDD1), U2.4 (PDEN)

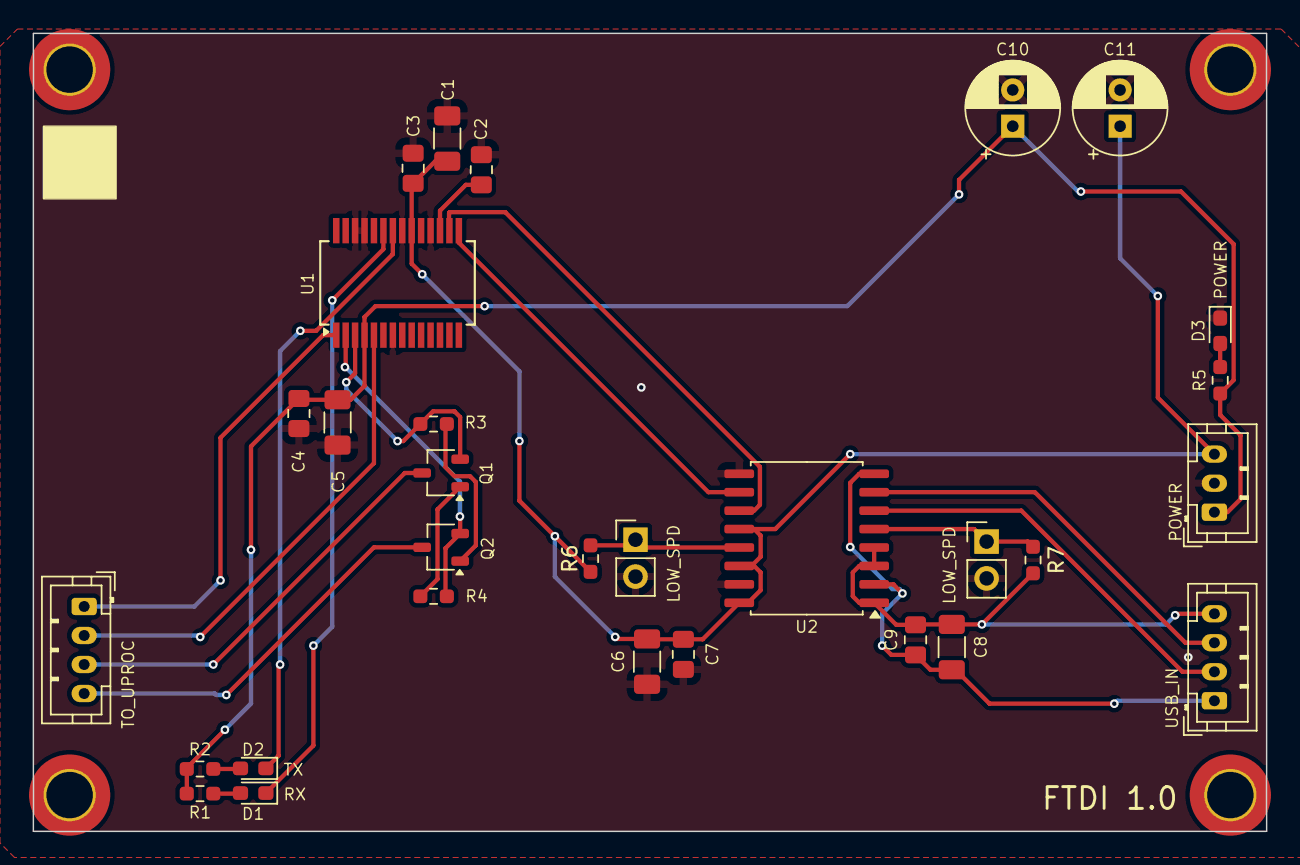
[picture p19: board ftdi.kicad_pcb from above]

Board: 2 copper layers, 85.0 x 55.0 mm, 34 parts (0 on the bottom side), 25 nets.

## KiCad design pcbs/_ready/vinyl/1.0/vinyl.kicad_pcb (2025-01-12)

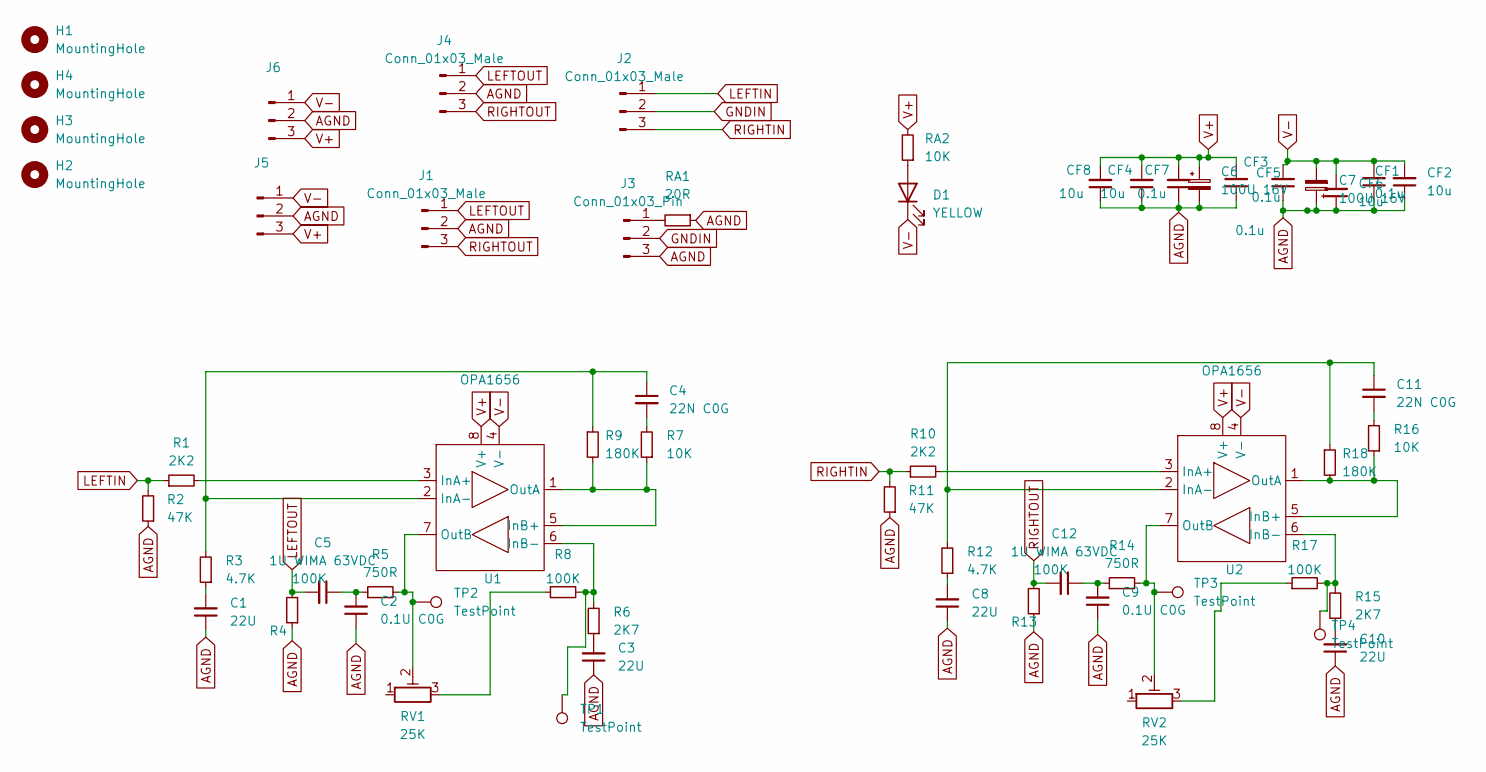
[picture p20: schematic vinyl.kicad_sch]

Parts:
C1, C3, C8, C10: 22U; CP_Radial_D6.3mm_P2.50mm
C2, C9: 0.1U C0G; C_1206_3216Metric_Pad1.33x1.80mm_HandSolder; Mouser 81-GRM3195C1H104GA5D
C4, C11: 22N C0G; C_0805_2012Metric_Pad1.18x1.45mm_HandSolder
C5, C12: 1U WIMA 63VDC; C_Rect_L7.2mm_W11.0mm_P5.00mm_FKS2_FKP2_MKS2_MKP2; Mouser 505-MKP2C0411NMN
C6, C7: 100U 16V; CP_Radial_D6.3mm_P2.50mm
CF1, CF3, CF5, CF7: 0.1u; C_0805_2012Metric_Pad1.18x1.45mm_HandSolder
CF2, CF4, CF6, CF8: 10u; C_1206_3216Metric_Pad1.33x1.80mm_HandSolder
D1: YELLOW; LED_0603_1608Metric_Pad1.05x0.95mm_HandSolder
H1, H2, H3, H4: MountingHole; MountingHole_3.2mm_M3_DIN965_Pad_TopOnly
J1, J2, J5, J6: Conn_01x03_Male; JST_PH_B3B-PH-K_1x03_P2.00mm_Vertical
J3: Conn_01x03_Pin; PinHeader_1x03_P2.54mm_Vertical
J4: Conn_01x03_Male; PinHeader_1x03_P2.54mm_Vertical
R1, R10: 2K2; R_0805_2012Metric_Pad1.20x1.40mm_HandSolder; Mouser 603-RT0805FRE072K2L
R2, R11: 47K; R_0805_2012Metric_Pad1.20x1.40mm_HandSolder; Mouser 603-RT0805FRE0747KL
R3, R12: 4.7K; R_0805_2012Metric_Pad1.20x1.40mm_HandSolder; Mouser 603-RT0805FRE074K7L
R4, R8, R13, R17: 100K; R_0805_2012Metric_Pad1.20x1.40mm_HandSolder; Mouser 603-RT0805FRE10100KL
R5, R14: 750R; R_0805_2012Metric_Pad1.20x1.40mm_HandSolder; Mouser 603-RT0805FRE07750RL
R6, R15: 2K7; R_0805_2012Metric_Pad1.20x1.40mm_HandSolder; Mouser 603-RT0805FRE072K7L
R7, R16: 10K; R_0805_2012Metric_Pad1.20x1.40mm_HandSolder; Mouser 603-RT0805FRE1310KL
R9, R18: 180K; R_0805_2012Metric_Pad1.20x1.40mm_HandSolder; Mouser 603-RT0805FRE07180KL
RA1: 20R; R_0603_1608Metric
RA2: 10K; R_0603_1608Metric
RV1, RV2: 25K; Potentiometer_Bourns_3296W_Vertical
TP1, TP2, TP3, TP4: TestPoint; TestPoint_THTPad_1.5x1.5mm_Drill0.7mm
U1, U2: OPA1656; DIP-8_W7.62mm_Socket; Mouser 595-OPA1656IDR

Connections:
AGND: C1.1, C2.1, C3.1, C6.2, C7.1, C8.1, C9.1, C10.1, CF1.1, CF2.1, CF3.1, CF4.1, CF5.1, CF6.1, CF7.1, CF8.1, J1.2, J3.3, J4.2, J5.2, J6.2, R2.1, R4.1, R11.1, R13.1, RA1.1
GNDIN: J2.2, J3.2
LEFTIN: J2.1, R1.1, R2.2
LEFTOUT: C5.2, J1.1, J4.1, R4.2
unnamed: C1.2, R3.1
unnamed: C2.2, C5.1, R5.1
unnamed: C3.2, R6.1
unnamed: C4.2, R7.2
unnamed: C8.2, R12.1
unnamed: C10.2, R15.1
unnamed: C11.2, R16.2
unnamed: C9.2, C12.1, R14.1
unnamed: D1.2 (A), RA2.1
unnamed: J3.1, RA1.2
unnamed: R8.1, RV1.3
unnamed: R17.1, RV2.3
unnamed: R1.2, U1.3 (InA+)
unnamed: C4.1, R3.2, R9.1, U1.2 (InA-)
unnamed: R7.1, R9.2, U1.1 (OutA), U1.5 (InB+)
unnamed: R6.2, R8.2, TP1.1, U1.6 (InB-)
unnamed: R5.2, RV1.2, TP2.1, U1.7 (OutB)
unnamed: R10.2, U2.3 (InA+)
unnamed: C11.1, R12.2, R18.1, U2.2 (InA-)
unnamed: R16.1, R18.2, U2.1 (OutA), U2.5 (InB+)
unnamed: R15.2, R17.2, TP4.1, U2.6 (InB-)
unnamed: R14.2, RV2.2, TP3.1, U2.7 (OutB)
RIGHTIN: J2.3, R10.1, R11.2
RIGHTOUT: C12.2, J1.3, J4.3, R13.2
V+: C6.1, CF3.2, CF4.2, CF7.2, CF8.2, J5.3, J6.3, RA2.2, U1.8 (V+), U2.8 (V+)
V-: C7.2, CF1.2, CF2.2, CF5.2, CF6.2, D1.1 (K), J5.1, J6.1, U1.4 (V-), U2.4 (V-)

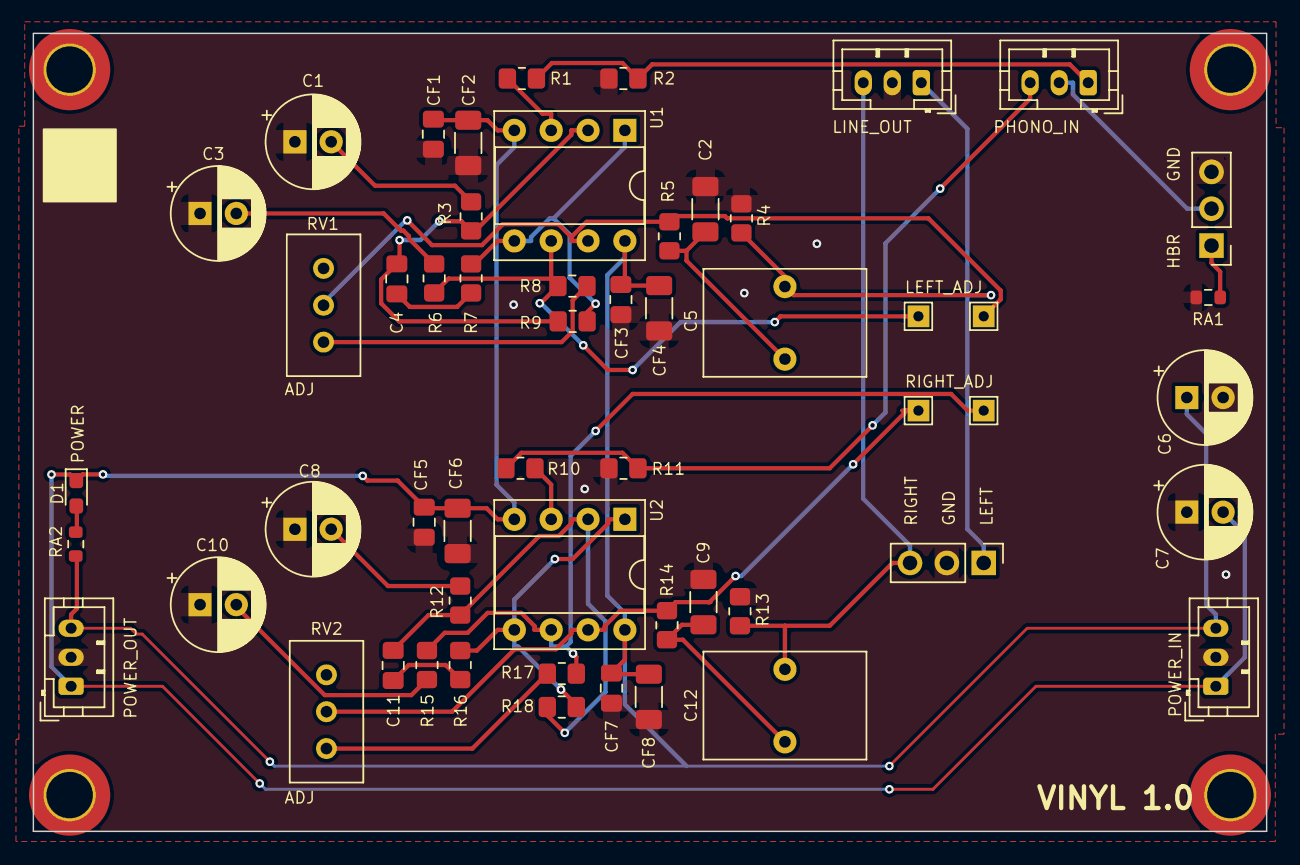
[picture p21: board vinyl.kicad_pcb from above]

Board: 2 copper layers, 85.0 x 55.0 mm, 59 parts (0 on the bottom side), 30 nets.

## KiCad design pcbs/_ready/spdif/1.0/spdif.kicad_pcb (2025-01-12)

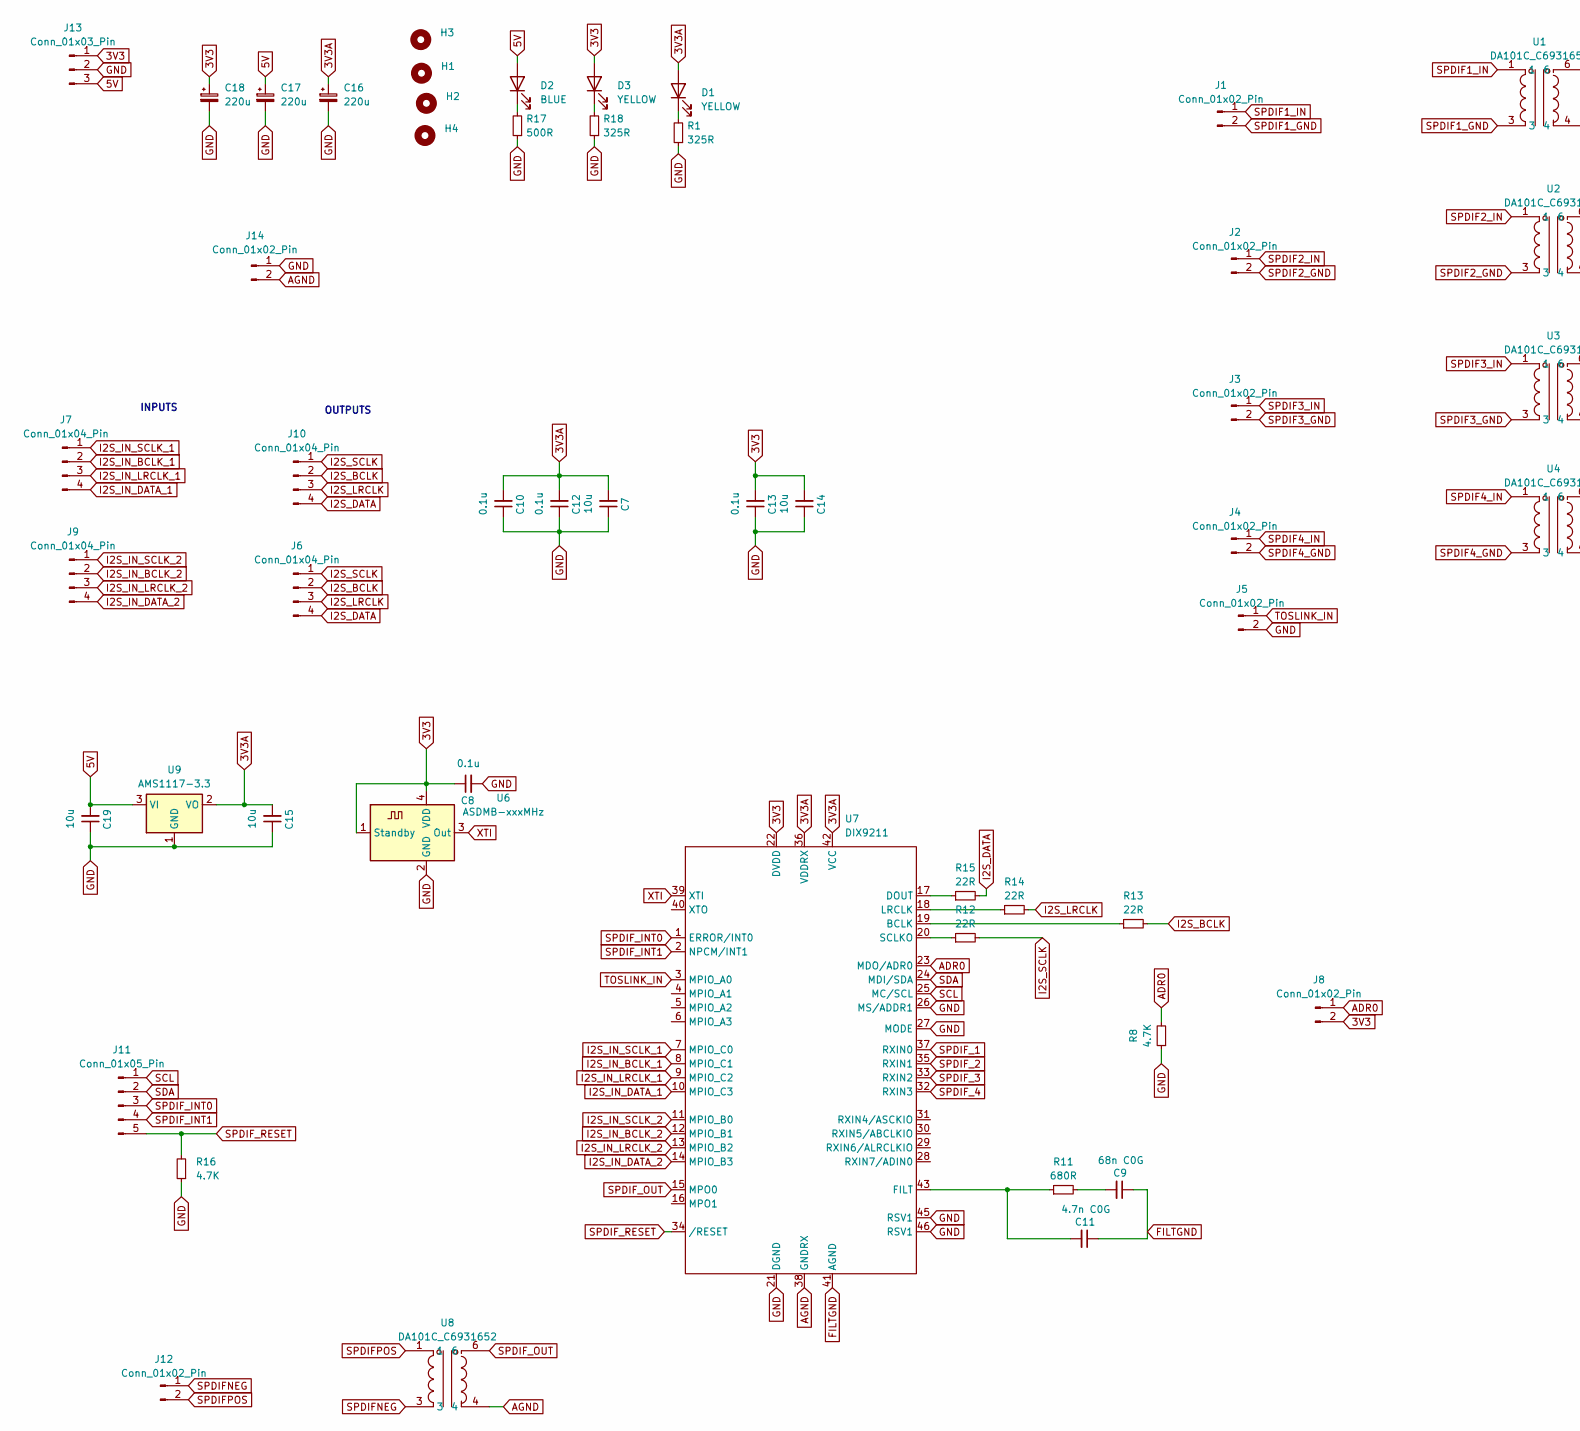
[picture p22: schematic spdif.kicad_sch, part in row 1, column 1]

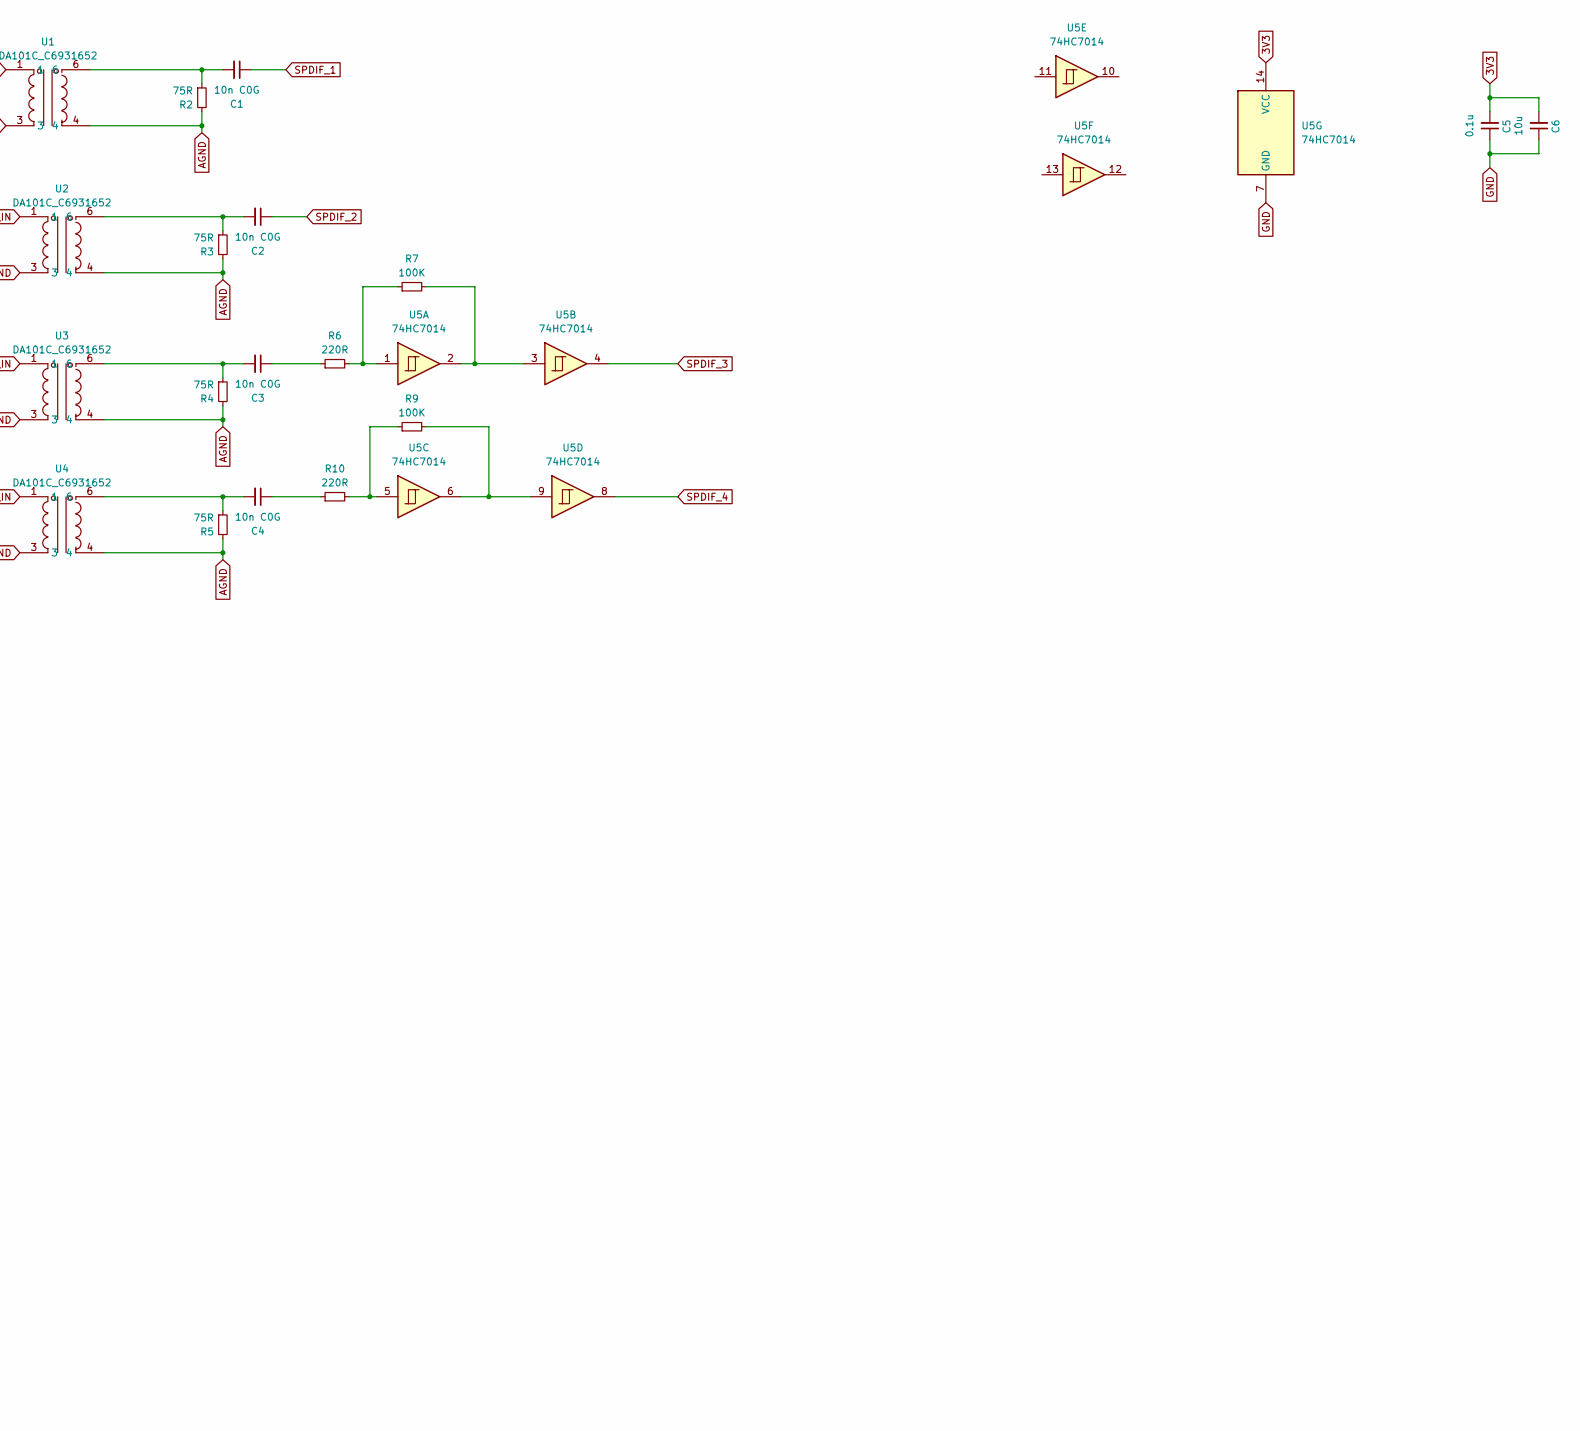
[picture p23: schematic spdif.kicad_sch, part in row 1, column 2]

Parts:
C1, C2, C3, C4: 10n C0G; C_0805_2012Metric_Pad1.18x1.45mm_HandSolder; Mouser 791-0805N103G250CT
C5, C8, C10, C12, C13: 0.1u; C_0805_2012Metric_Pad1.18x1.45mm_HandSolder
C6, C7, C14, C15, C19: 10u; C_1206_3216Metric_Pad1.33x1.80mm_HandSolder
C9: 68n C0G; C_1206_3216Metric; Mouser 81-GRM3195C1H683JA5D
C11: 4.7n C0G; C_0603_1608Metric; Mouser 791-0603N472F500CT
C16, C17, C18: 220u; CP_Radial_D6.3mm_P2.50mm
D1, D3: YELLOW; LED_0603_1608Metric
D2: BLUE; LED_0603_1608Metric
H1, H2, H3, H4: MountingHole; MountingHole_3.2mm_M3_DIN965_Pad_TopOnly
J1, J2, J3, J4, J5, J12: Conn_01x02_Pin; JST_XH_B2B-XH-A_1x02_P2.50mm_Vertical
J6: Conn_01x04_Pin; PinHeader_1x04_P2.54mm_Vertical
J7, J9, J10: Conn_01x04_Pin; JST_PH_B4B-PH-K_1x04_P2.00mm_Vertical
J8, J14: Conn_01x02_Pin; PinHeader_1x02_P2.54mm_Vertical
J11: Conn_01x05_Pin; JST_PH_B5B-PH-K_1x05_P2.00mm_Vertical
J13: Conn_01x03_Pin; JST_PH_B3B-PH-K_1x03_P2.00mm_Vertical
R1, R18: 325R; R_0603_1608Metric_Pad0.98x0.95mm_HandSolder
R2, R3, R4, R5: 75R; R_0603_1608Metric_Pad0.98x0.95mm_HandSolder; Mouser 71-CRCW0603-75-E3
R6, R10: 220R; R_0603_1608Metric_Pad0.98x0.95mm_HandSolder; Mouser 71-CRCW0603-75-E3
R7, R9: 100K; R_0603_1608Metric_Pad0.98x0.95mm_HandSolder; Mouser 71-CRCW0603-75-E3
R8, R16: 4.7K; R_0603_1608Metric
R11: 680R; R_0603_1608Metric; Mouser 603-RT0603FRE07680RL
R12: 22R; R_0805_2012Metric
R13, R14, R15: 22R; R_0805_2012Metric; Mouser 603-RT0805FRE0722RL
R17: 500R; R_0603_1608Metric_Pad0.98x0.95mm_HandSolder
U1, U2, U3, U4, U8: DA101C_C6931652; XFMR-TH_4P-L9.5-W9.0-P5.08-LS10.2_C9900096976; LCSC Part C6931652
U5: 74HC7014; TSSOP-14_4.4x5mm_P0.65mm; Mouser 771-74HC7014D-T
U6: ASDMB-xxxMHz; Oscillator_SMD_Abracon_ASE-4Pin_3.2x2.5mm; Mouser 346-3225Z24.5760C1KX
U7: DIX9211; LQFP-48_7x7mm_P0.5mm; Mouser 595-DIX9211PTR
U9: AMS1117-3.3; SOT-223-3_TabPin2

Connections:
3V3: C5.2, C6.2, C8.1, C13.2, C14.2, C18.1, D3.2 (A), J8.2, J13.1, U5.14 (VCC), U6.1 (Standby), U6.4 (VDD), U7.22 (DVDD)
3V3A: C7.2, C10.2, C12.2, C15.2, C16.1, D1.2 (A), U7.36 (VDDRX), U7.42 (VCC), U9.2 (VO)
5V: C17.1, C19.2, D2.2 (A), J13.3, U9.3 (VI)
ADR0: J8.1, R8.2, U7.23 (MDO/ADR0)
AGND: J14.2, R2.2, R3.2, R4.2, R5.2, U1.4, U2.4, U3.4, U4.4, U7.38 (GNDRX), U8.4
FILTGND: C9.1, C11.1, U7.41 (AGND)
GND: C5.1, C6.1, C7.1, C8.2, C10.1, C12.1, C13.1, C14.1, C15.1, C16.2, C17.2, C18.2, C19.1, J5.2, J13.2, J14.1, R1.1, R8.1, R16.1, R17.1, R18.1, U5.7 (GND), U6.2 (GND), U7.21 (DGND), U7.26 (MS/ADDR1), U7.27 (MODE), U7.45 (RSV1), U7.46 (RSV1), U9.1 (GND)
I2S_BCLK: J6.2, J10.2, R13.2
I2S_DATA: J6.4, J10.4, R15.2
I2S_IN_BCLK_1: J7.2, U7.8 (MPIO_C1)
I2S_IN_BCLK_2: J9.2, U7.12 (MPIO_B1)
I2S_IN_DATA_1: J7.4, U7.10 (MPIO_C3)
I2S_IN_DATA_2: J9.4, U7.14 (MPIO_B3)
I2S_IN_LRCLK_1: J7.3, U7.9 (MPIO_C2)
I2S_IN_LRCLK_2: J9.3, U7.13 (MPIO_B2)
I2S_IN_SCLK_1: J7.1, U7.7 (MPIO_C0)
I2S_IN_SCLK_2: J9.1, U7.11 (MPIO_B0)
I2S_LRCLK: J6.3, J10.3, R14.2
I2S_SCLK: J6.1, J10.1, R12.2
unnamed: C1.2, R2.1, U1.6
unnamed: C2.2, R3.1, U2.6
unnamed: C3.1, R6.1
unnamed: C3.2, R4.1, U3.6
unnamed: C4.1, R10.1
unnamed: C4.2, R5.1, U4.6
unnamed: C9.2, R11.2
unnamed: D1.1 (K), R1.2
unnamed: D2.1 (K), R17.2
unnamed: D3.1 (K), R18.2
unnamed: R6.2, R7.1, U5.1
unnamed: R7.2, U5.2, U5.3
unnamed: R9.2, U5.6, U5.9
unnamed: R9.1, R10.2, U5.5
unnamed: R13.1, U7.19 (BCLK)
unnamed: R15.1, U7.17 (DOUT)
unnamed: C11.2, R11.1, U7.43 (FILT)
unnamed: R14.1, U7.18 (LRCLK)
unnamed: R12.1, U7.20 (SCLKO)
SCL: J11.1, U7.25 (MC/SCL)
SDA: J11.2, U7.24 (MDI/SDA)
SPDIF1_GND: J1.2, U1.3
SPDIF1_IN: J1.1, U1.1
SPDIF2_GND: J2.2, U2.3
SPDIF2_IN: J2.1, U2.1
SPDIF3_GND: J3.2, U3.3
SPDIF3_IN: J3.1, U3.1
SPDIF4_GND: J4.2, U4.3
SPDIF4_IN: J4.1, U4.1
SPDIFNEG: J12.1, U8.3
SPDIFPOS: J12.2, U8.1
SPDIF_1: C1.1, U7.37 (RXIN0)
SPDIF_2: C2.1, U7.35 (RXIN1)
SPDIF_3: U5.4, U7.33 (RXIN2)
SPDIF_4: U5.8, U7.32 (RXIN3)
SPDIF_INT0: J11.3, U7.1 (ERROR/INT0)
SPDIF_INT1: J11.4, U7.2 (NPCM/INT1)
SPDIF_OUT: U7.15 (MPO0), U8.6
SPDIF_RESET: J11.5, R16.2, U7.34 (/RESET)
TOSLINK_IN: J5.1, U7.3 (MPIO_A0)
XTI: U6.3 (Out), U7.39 (XTI)

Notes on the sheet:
OUTPUTS
INPUTS

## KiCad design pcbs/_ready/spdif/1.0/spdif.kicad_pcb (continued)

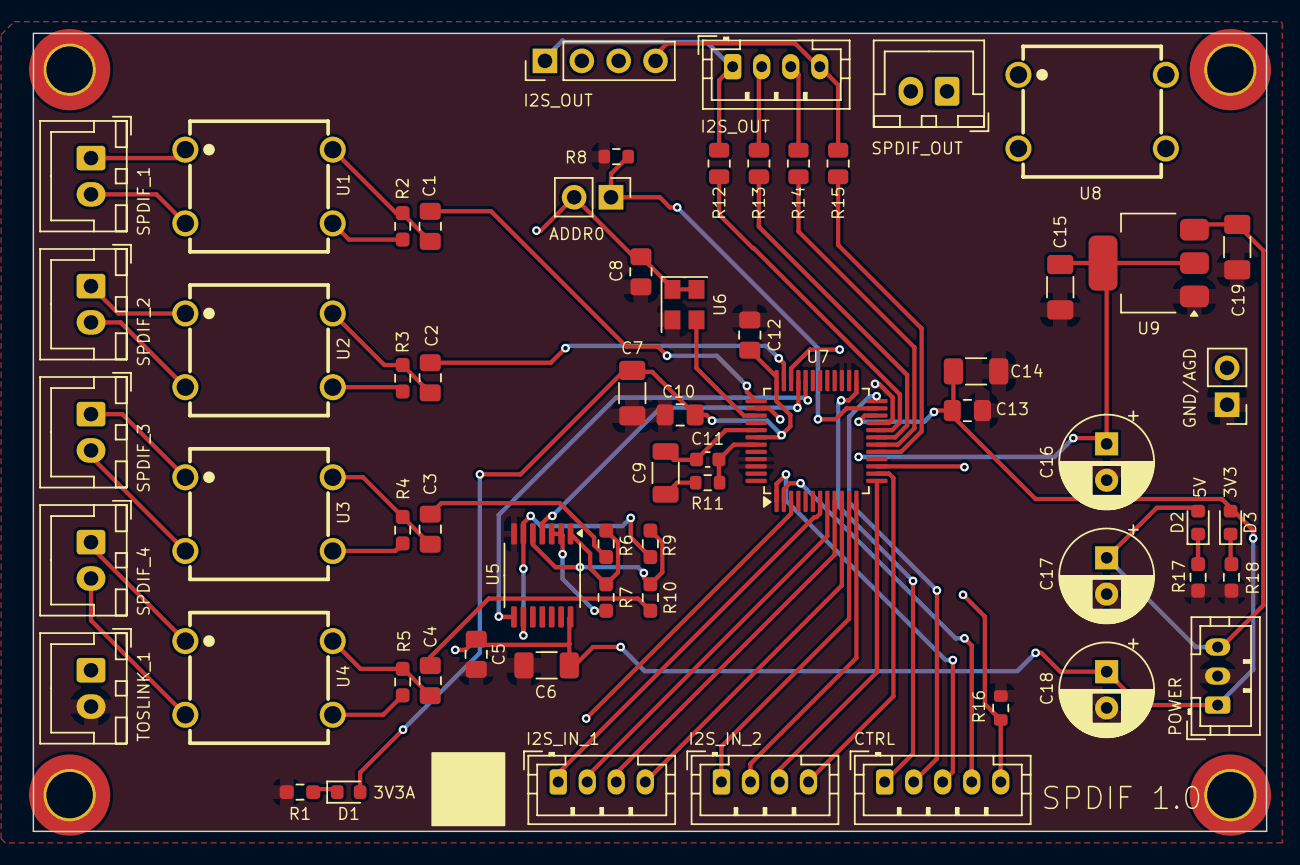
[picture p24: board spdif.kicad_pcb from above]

Board: 4 copper layers, 85.0 x 55.0 mm, 67 parts (0 on the bottom side), 60 nets.

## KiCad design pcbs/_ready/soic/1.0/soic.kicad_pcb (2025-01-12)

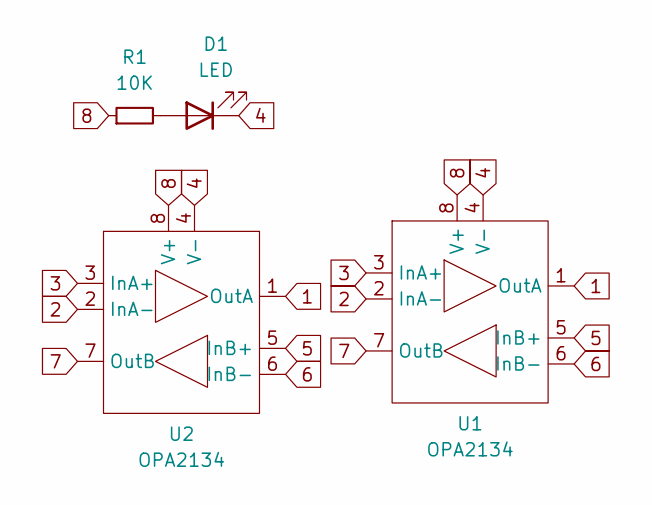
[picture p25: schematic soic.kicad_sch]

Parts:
D1: LED; LED_0603_1608Metric
R1: 10K; R_0603_1608Metric
U1: OPA2134; DIP-8_W7.62mm_Socket
U2: OPA2134; SOIC-8_3.9x4.9mm_P1.27mm

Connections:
1: U1.1 (OutA), U2.1 (OutA)
2: U1.2 (InA-), U2.2 (InA-)
3: U1.3 (InA+), U2.3 (InA+)
4: D1.1 (K), U1.4 (V-), U2.4 (V-)
5: U1.5 (InB+), U2.5 (InB+)
6: U1.6 (InB-), U2.6 (InB-)
7: U1.7 (OutB), U2.7 (OutB)
8: R1.1, U1.8 (V+), U2.8 (V+)
unnamed: D1.2 (A), R1.2

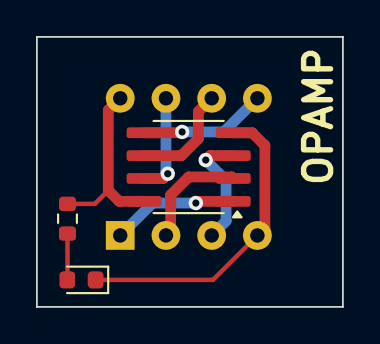
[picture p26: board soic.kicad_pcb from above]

Board: 2 copper layers, 17.0 x 15.0 mm, 4 parts (0 on the bottom side), 9 nets.

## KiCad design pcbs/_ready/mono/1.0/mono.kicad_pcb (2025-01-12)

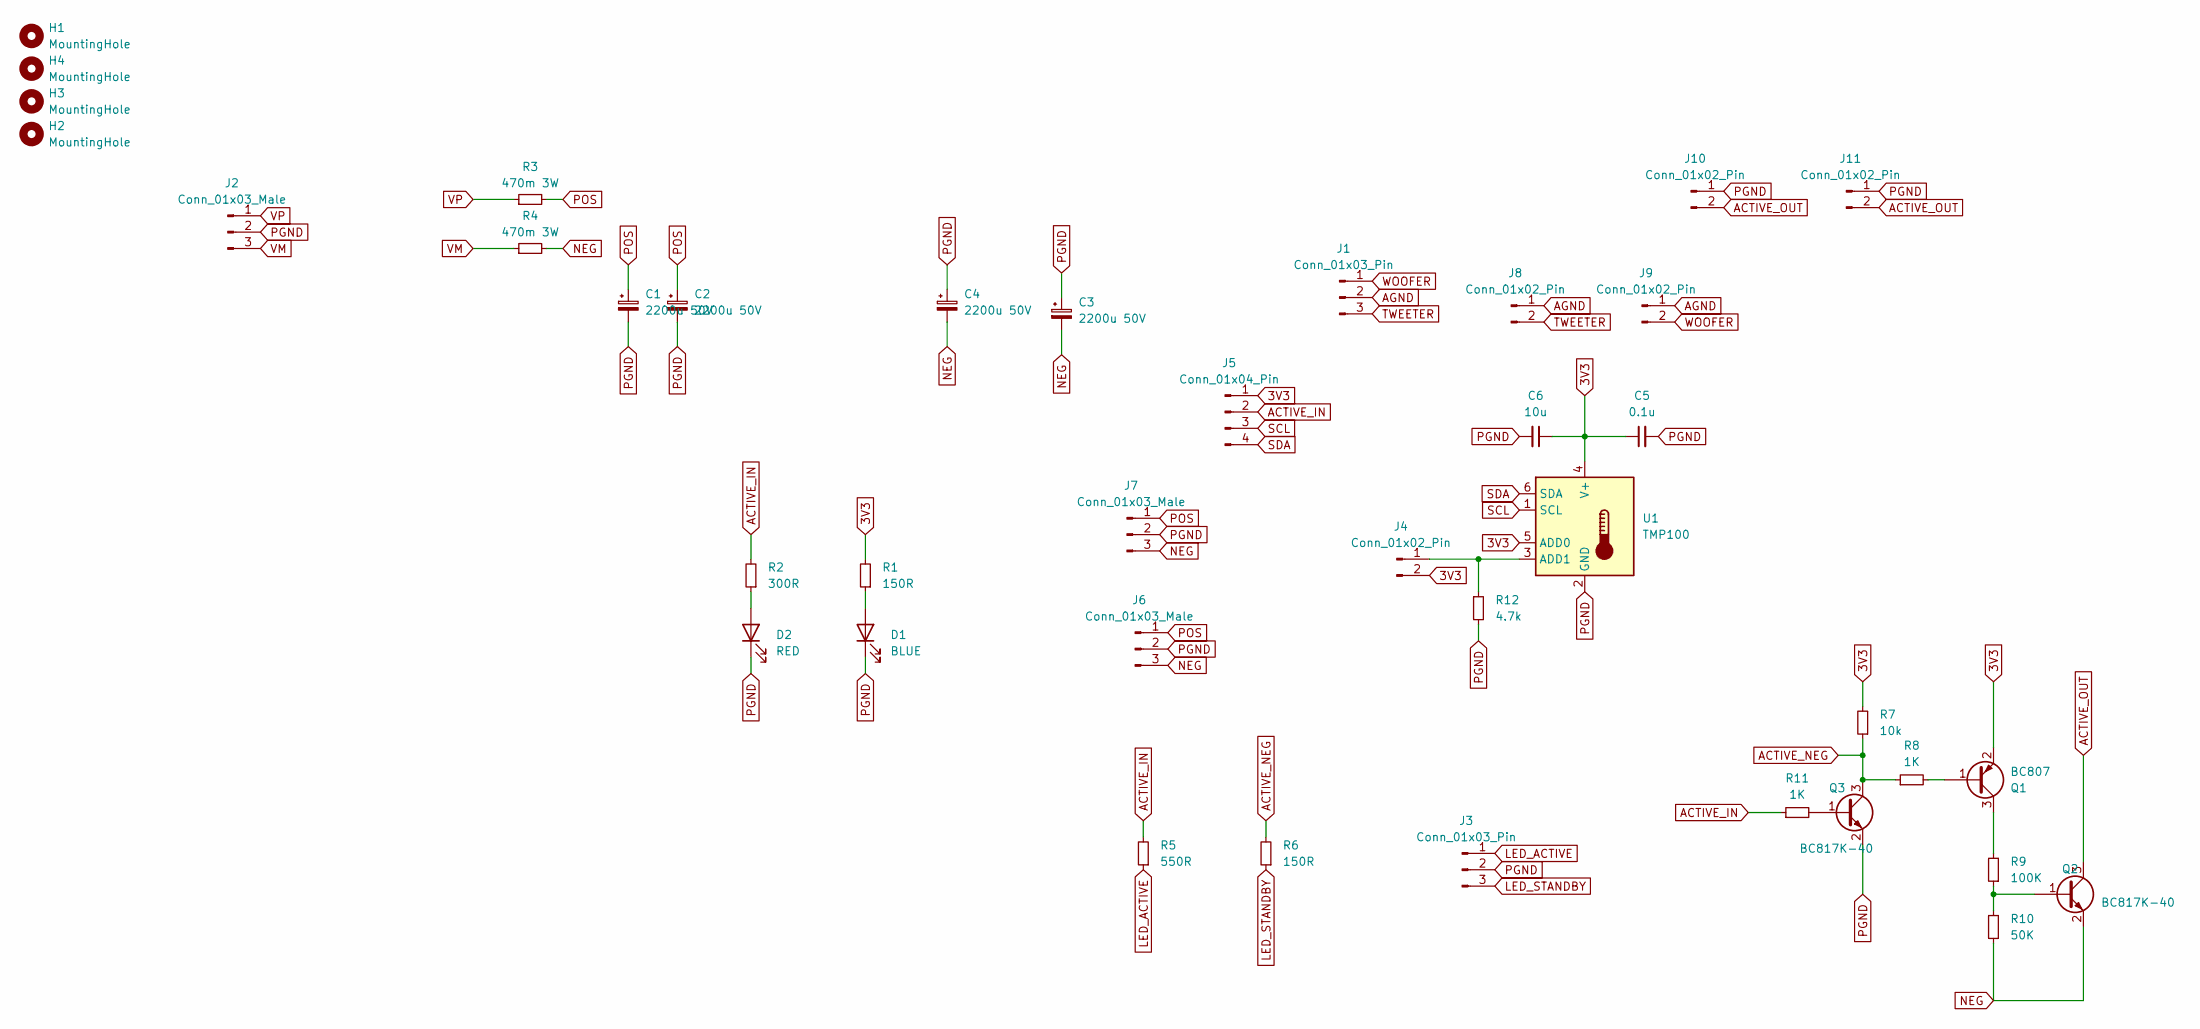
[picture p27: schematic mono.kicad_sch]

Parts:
C1, C2, C3, C4: 2200u 50V; CP_Radial_D16.0mm_P7.50mm; Mouser 80-ESH228M050AM3AA
C5: 0.1u; C_0805_2012Metric_Pad1.18x1.45mm_HandSolder
C6: 10u; C_1206_3216Metric_Pad1.33x1.80mm_HandSolder
D1: BLUE; LED_0603_1608Metric_Pad1.05x0.95mm_HandSolder
D2: RED; LED_0603_1608Metric_Pad1.05x0.95mm_HandSolder
H1, H2, H3, H4: MountingHole; MountingHole_3.2mm_M3_DIN965_Pad_TopOnly
J1, J3: Conn_01x03_Pin; JST_PH_B3B-PH-K_1x03_P2.00mm_Vertical
J2, J6, J7: Conn_01x03_Male; JST_VH_B3P-VH-B_1x03_P3.96mm_Vertical
J4: Conn_01x02_Pin; PinHeader_1x02_P2.54mm_Vertical
J5: Conn_01x04_Pin; JST_PH_B4B-PH-K_1x04_P2.00mm_Vertical
J8, J9, J10, J11: Conn_01x02_Pin; JST_PH_B2B-PH-K_1x02_P2.00mm_Vertical
Q1: BC807; TSOT-23; Mouser 637-BC807-16
Q2, Q3: BC817K-40; TSOT-23; Mouser 637-BC817K-40
R1, R6: 150R; R_0603_1608Metric_Pad0.98x0.95mm_HandSolder
R2: 300R; R_0603_1608Metric_Pad0.98x0.95mm_HandSolder
R3, R4: 470m 3W; R_1218_3246Metric_Pad1.22x4.75mm_HandSolder; Mouser RLW73PA3FR47TDF
R5: 550R; R_0603_1608Metric_Pad0.98x0.95mm_HandSolder
R7: 10k; R_0603_1608Metric_Pad0.98x0.95mm_HandSolder
R8, R11: 1K; R_0603_1608Metric_Pad0.98x0.95mm_HandSolder
R9: 100K; R_0603_1608Metric_Pad0.98x0.95mm_HandSolder
R10: 50K; R_0603_1608Metric_Pad0.98x0.95mm_HandSolder
R12: 4.7k; R_0603_1608Metric_Pad0.98x0.95mm_HandSolder
U1: TMP100; SOT-23-6

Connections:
3V3: C5.1, C6.1, J4.2, J5.1, Q1.2 (E), R1.2, R7.2, U1.4 (V+), U1.5 (ADD0)
ACTIVE_IN: J5.2, R2.2, R5.2, R11.1
ACTIVE_NEG: Q3.3 (C), R6.2, R7.1, R8.1
ACTIVE_OUT: J10.2, J11.2, Q2.3 (C)
AGND: J1.2, J8.1, J9.1
LED_ACTIVE: J3.1, R5.1
LED_STANDBY: J3.3, R6.1
NEG: C3.2, C4.2, J6.3, J7.3, Q2.2 (E), R4.2, R10.1
unnamed: D1.2 (A), R1.1
unnamed: D2.2 (A), R2.1
unnamed: J4.1, R12.1, U1.3 (ADD1)
unnamed: Q1.1 (B), R8.2
unnamed: Q1.3 (C), R9.2
unnamed: Q2.1 (B), R9.1, R10.2
unnamed: Q3.1 (B), R11.2
PGND: C1.2, C2.2, C3.1, C4.1, C5.2, C6.2, D1.1 (K), D2.1 (K), J2.2, J3.2, J6.2, J7.2, J10.1, J11.1, Q3.2 (E), R12.2, U1.2 (GND)
POS: C1.1, C2.1, J6.1, J7.1, R3.2
SCL: J5.3, U1.1 (SCL)
SDA: J5.4, U1.6 (SDA)
TWEETER: J1.3, J8.2
VM: J2.3, R4.1
VP: J2.1, R3.1
WOOFER: J1.1, J9.2


Board: 2 copper layers, 100.0 x 45.0 mm, 39 parts (0 on the bottom side), 23 nets.

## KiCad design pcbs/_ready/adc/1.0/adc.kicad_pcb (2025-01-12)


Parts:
C1: 0.1u; C_0805_2012Metric_Pad1.18x1.45mm_HandSolder; Mouser 791-0805N103G250CT
C2, C4, C11: 470u; CP_Radial_D6.3mm_P2.50mm
C3, C6, C8, C9, C12, C14: 10u; C_1206_3216Metric_Pad1.33x1.80mm_HandSolder
C5, C7, C10, C13: 0.1u; C_0805_2012Metric_Pad1.18x1.45mm_HandSolder
C15: 1u; C_1206_3216Metric_Pad1.33x1.80mm_HandSolder
C16, C17, C18, C19: 10n C0G; C_0805_2012Metric_Pad1.18x1.45mm_HandSolder; Mouser 791-0805N103G250CT
C20, C21, C22, C23: 10u NICHICON 25V; CP_Radial_D5.0mm_P2.00mm
D1, D3: BLUE; LED_0603_1608Metric
D2: YELLOW; LED_0603_1608Metric
H1, H2, H3, H4: MountingHole; MountingHole_3.2mm_M3_DIN965_Pad_TopOnly
J1, J4: Conn_01x04_Pin; JST_PH_B4B-PH-K_1x04_P2.00mm_Vertical
J2: Conn_01x02_Male; PinHeader_1x02_P2.54mm_Vertical
J3, J5, J6: Conn_01x03_Pin; JST_PH_B3B-PH-K_1x03_P2.00mm_Vertical
R1: 150R; R_0603_1608Metric_Pad0.98x0.95mm_HandSolder
R2: 650R; R_0603_1608Metric_Pad0.98x0.95mm_HandSolder
R3: 1.3K; R_0603_1608Metric_Pad0.98x0.95mm_HandSolder
R4, R5, R6, R7: 22R; R_0805_2012Metric_Pad1.20x1.40mm_HandSolder; Mouser 603-RT0805FRE0722RL
R8, R9, R10, R11: 100R; R_0805_2012Metric_Pad1.20x1.40mm_HandSolder; Mouser 603-RT0805FRE13100RL
U1: ASDMB-xxxMHz; Oscillator_SMD_Abracon_ASE-4Pin_3.2x2.5mm; Mouser 346-3225Z24.5760C1KX
U2: ZLDO1117QG33TA; SOT-223-3_TabPin2
U3: PCM1863; TSSOP-30_4.4x7.8mm_P0.5mm; Mouser 595-PCM1863DBT

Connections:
3V3: C1.1, C4.1, C5.1, C6.1, C7.1, C8.1, J3.1, R1.2, U1.1 (Standby), U1.4 (VDD), U3.13 (DVDD), U3.14 (IOVDD)
3V3A: C2.1, C9.2, C13.1, C14.1, R2.2, U2.2 (VO), U3.8 (AVDD)
5V: C3.2, C11.1, J3.3, R3.2, U2.3 (VI)
ADC_GPIO1: J4.3, U3.21 (GPIO1/INTA/DMI)
ADC_INT: J4.4, U3.20 (GPIO2/INTB/DMCLK)
AGND: C16.1, C17.2, C18.1, C19.2, J2.1, J5.2, J6.2, U3.7 (AGND), U3.27 (VINL4), U3.28 (VINR4), U3.29 (VINL3), U3.30 (VINR3)
GND: C1.2, C3.1, C4.2, C5.2, C6.2, C7.2, C8.2, C9.1, C10.2, C11.2, C12.2, C13.2, C14.2, C15.2, D1.1 (K), D2.1 (K), D3.1 (K), J2.2, J3.2, U1.2 (GND), U2.1 (GND), U3.12 (DGND), U3.25 (MS/AD), U3.26 (MD0)
GNDA: C2.2
I2S_BCLK_OUT: J1.2, R5.2
I2S_DATA_OUT: J1.4, R7.2
I2S_LRCLK_OUT: J1.3, R6.2
I2S_MCLK_OUT: J1.1, R4.2
INT: U3.19 (GPIO3/INTC)
LDO: C10.1, C12.1, U3.11 (LDO)
LEFT_IN: C22.1, J6.1
MIC_LEFT_IN: C20.1, J5.1
MIC_RIGHT_IN: C21.1, J5.3
unnamed: C20.2, R8.1
unnamed: C21.2, R9.1
unnamed: C22.2, R10.1
unnamed: C23.2, R11.1
unnamed: D1.2 (A), R1.1
unnamed: D2.2 (A), R2.1
unnamed: D3.2 (A), R3.1
unnamed: R5.1, U3.17 (BCLK)
unnamed: R7.1, U3.18 (DOUT)
unnamed: R6.1, U3.16 (LRCLK)
unnamed: R4.1, U3.22 (MOSI/GPIO0/DMIN2)
unnamed: C18.2, R10.2, U3.3 (VINL1)
unnamed: C16.2, R8.2, U3.1 (VINL2)
unnamed: C19.1, R11.2, U3.4 (VINR1)
unnamed: C17.1, R9.2, U3.2 (VINR2)
RIGHT_IN: C23.1, J6.3
SCL: J4.1, U3.24 (MC/SCL)
SCLKI: U1.3 (Out), U3.15 (SCLKI)
SDA: J4.2, U3.23 (MOSI/SDA)
VREF: C15.1, U3.6 (VREF)


Board: 2 copper layers, 85.0 x 55.0 mm, 50 parts (0 on the bottom side), 35 nets.

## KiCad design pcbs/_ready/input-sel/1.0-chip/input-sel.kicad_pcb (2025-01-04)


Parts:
C1, C2, C3, C4, C5, C6, C7, C8, C9, C10, C11, C12, C23, C24: 0.1u 50V C0G; C_1206_3216Metric_Pad1.33x1.80mm_HandSolder; Mouser 81-GRM3195C1H104JA5D
C13, C18, C19, C21: 4.7u 35V Nichicon Muse; CP_Radial_D5.0mm_P2.00mm
C14, C17, C20: 10U; C_1206_3216Metric_Pad1.33x1.80mm_HandSolder
C15, C16: 0.1u; C_0805_2012Metric_Pad1.18x1.45mm_HandSolder
C22: 470u; CP_Radial_D6.3mm_P2.50mm
D1: RED; LED_0805_2012Metric
H1, H2, H3, H4: MountingHole; MountingHole_3.2mm_M3_DIN965_Pad_TopOnly
J1, J2, J3, J5, J6, J8: Conn_01x03_Pin; JST_PH_B3B-PH-K_1x03_P2.00mm_Vertical
J4: Conn_01x03_Male; JST_PH_B3B-PH-K_1x03_P2.00mm_Vertical
J9: Conn_01x04_Pin; JST_PH_B4B-PH-K_1x04_P2.00mm_Vertical
J10: Conn_01x02_Male; JST_PH_B2B-PH-K_1x02_P2.00mm_Vertical
R1, R2, R3, R5: 100K; R_0603_1608Metric_Pad0.98x0.95mm_HandSolder; Mouser 603-AT0603FRE07100KL
R4: 75R; R_0603_1608Metric_Pad0.98x0.95mm_HandSolder
U1, U2: NJM2750; SOP-16_4.4x10.4mm_P1.27mm; Mouser NJM2750M

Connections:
AGND: C14.2, C15.2, C16.2, C17.1, C20.1, C22.2, D1.1 (K), J1.2, J2.2, J3.2, J4.2, J5.2, J6.2, J8.2, R1.1, R2.1, R3.1, R5.1, U1.1 (IN1L), U1.6 (IN1R), U1.16 (GND), U2.16 (GND); also elsewhere on the board
CTRL1: J9.1, U1.2 (CNT1)
CTRL2: J9.2, U1.4 (CNT2)
CTRL3: J9.3, U2.2 (CNT1)
CTRL4: J9.4, U2.4 (CNT2)
EXPAND_L: C13.1, C23.1
EXPAND_R: C19.1, C24.1
unnamed: C11.2, U2.5 (IN4L)
unnamed: C12.2, U2.8 (IN4L)
unnamed: C23.2, U1.5 (IN4L)
unnamed: C24.2, U1.8 (IN4L)
unnamed: D1.2 (A), R4.1
unnamed: C1.2, U1.3 (IN2L)
unnamed: C2.2, U1.7 (IN2R)
unnamed: C3.2, U1.13 (IN3L)
unnamed: C7.2, U1.9 (IN3R)
unnamed: C21.2, R5.2, U1.15 (OUTL)
unnamed: C18.2, R2.2, U1.11 (OUTR)
unnamed: C20.2, U1.12 (VREF)
unnamed: C8.2, U2.1 (IN1L)
unnamed: C9.2, U2.6 (IN1R)
unnamed: C4.2, U2.3 (IN2L)
unnamed: C5.2, U2.7 (IN2R)
unnamed: C6.2, U2.13 (IN3L)
unnamed: C10.2, U2.9 (IN3R)
unnamed: C13.2, R1.2, U2.15 (OUTL)
unnamed: C19.2, R3.2, U2.11 (OUTR)
unnamed: C17.2, U2.12 (VREF)
OUT_L: C21.1, J8.1
OUT_R: C18.1, J8.3
RCA1_L: C1.1, J1.1
RCA1_R: C2.1, J1.3
RCA2_L: C3.1, J2.1
RCA2_R: C7.1, J2.3
RCA3_L: C8.1, J3.1
RCA3_R: C9.1, J3.3
RCA5_L: C6.1, J5.1
RCA5_R: C10.1, J5.3
RCA6_L: C11.1, J6.1
RCA6_R: C12.1, J6.3
SCL: J10.1
SDA: J10.2

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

Board: 2 copper layers, 85.0 x 55.0 mm, 46 parts (0 on the bottom side), 43 nets.

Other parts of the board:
J7: Conn_01x03_Male; JST_PH_B3B-PH-K_1x03_P2.00mm_Vertical

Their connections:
AGND: J7.2; also elsewhere on the board

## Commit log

2025-01-04 Updates to PCBs
    [ADC.kicad_pcb, ADC.kicad_sch, ChannelSelector.kicad_pcb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]
2025-01-04 Moving PCBs
    [ADC.kicad_pcb, ADC.kicad_sch, ChannelSelector.kicad_pcb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]
2025-01-04 updating names
    [DSP.kicad_pcb, DSP.kicad_sch]
2025-01-04 Updating PCBs
    [ADC.kicad_pcb, ADC.kicad_sch, DAC.kicad_pcb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]
2025-01-04 Updated screenshots
    [ADC.kicad_pcb, ADC.kicad_sch, ChannelSelector.kicad_pcb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]
2025-01-05 Updating readmes
    [dsp.kicad_pcb, dsp.kicad_sch]
2025-01-05 Updating readme files
    [uproc.kicad_sch]
2025-01-12 More work on PCBs
    [SPDIF.kicad_pcb, SPDIF.kicad_sch, adc.kicad_pcb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]
